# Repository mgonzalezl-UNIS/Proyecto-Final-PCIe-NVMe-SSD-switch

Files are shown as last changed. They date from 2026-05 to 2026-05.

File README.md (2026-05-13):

# Proyecto Final de Electrónica 2 y Diseño Electrónico 1 - PCIe to NVMe M.2 SSD Switch

<p align="center">
  <em>Universidad del Istmo de Guatemala</em><br>
  <em>Facultad de Ingeniería</em><br>
  <em>Proyecto Final</em><br>
  <em>Electrónica 2 y Diseño Electrónico 1</em>
</p>

<div align="center">
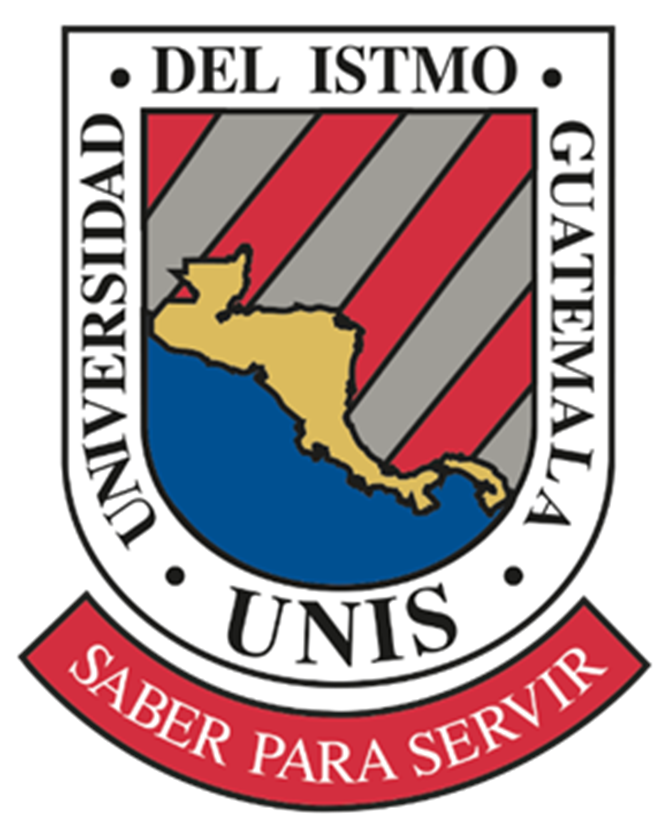
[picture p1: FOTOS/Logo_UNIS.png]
Logo UNIS
  
</div>

<p align="center">
  <em>Maximiliano González</em><br>
  <em>mayo de 2026</em>
</p>

## Descripción general

<div align="center">
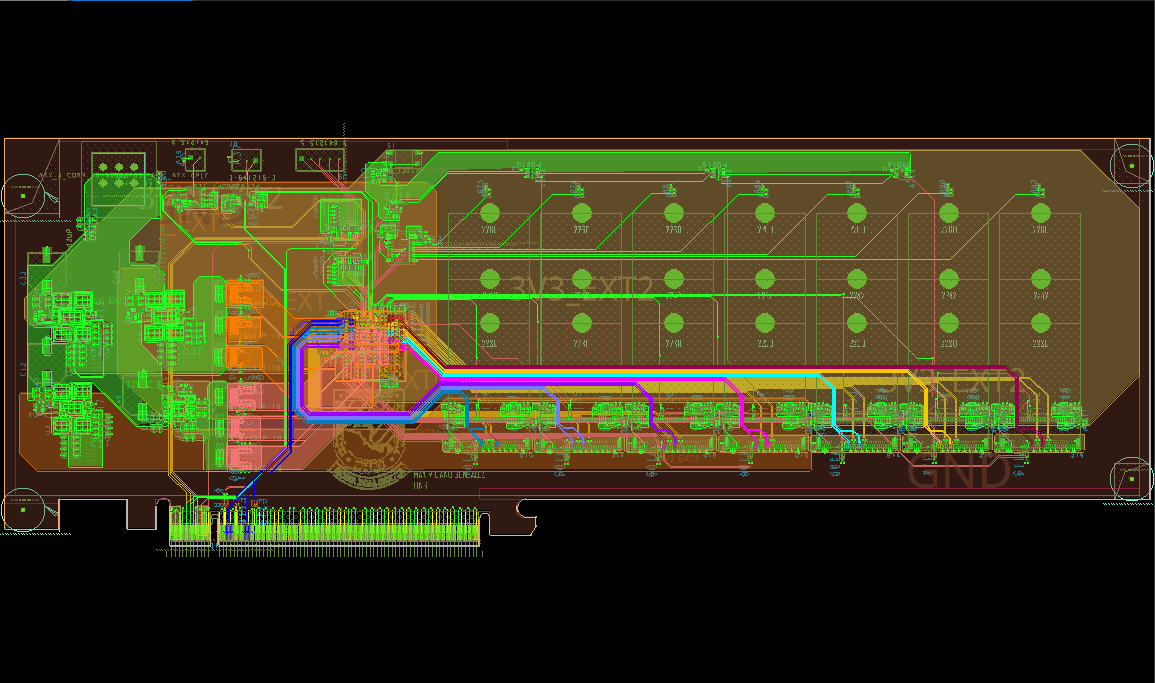
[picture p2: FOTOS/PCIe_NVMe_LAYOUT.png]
PCB LAYOUT
  
</div>

Este repositorio documenta el diseño de una tarjeta personalizada con **switch PCIe Gen 3 para expansión de SSDs NVMe M.2**. El objetivo del proyecto es tomar una conexión PCIe desde el host y distribuirla mediante un switch PCIe para conectar varios SSDs NVMe M.2 en una sola tarjeta.

La tarjeta se desarrolló como proyecto final de electrónica y se enfoca en el trabajo práctico necesario para un sistema PCIe de alta velocidad: captura esquemática, diseño del árbol de potencia, planeación de carriles PCIe, distribución del reloj de referencia, manejo de reset/wake/presence, bus SMBus/I2C, conectores M.2, restricciones de layout, stack-up e integración mecánica. Es importante notar que el diseno final **no** soporta **hot plug**.

## Tabla de Contenido

- [Versión en Español](#switch-pcie-a-nvme-m2-ssd)
  - [Descripción general](#descripción-general)
  - [Project Images](#project-images)
    - [Top Layer](#top-layer)
    - [GND02 Layer](#gnd02-layer)
    - [ART03 Layer](#art03-layer)
    - [ART04 Layer](#art04-layer)
    - [PWR05 Layer](#pwr05-layer)
    - [Bottom Layer](#bottom-layer)
  - [Concepto 3D](#concepto-3D)
    - [Isometric View](#isometric-view)
    - [Front View](#front-View)
    - [Back View](#back-view)
  - [Chip PCIe principal](#chip-pcie-principal)
  - [Objetivos del proyecto](#objetivos-del-proyecto)
  - [Arquitectura general](#arquitectura-general)
  - [Bloques principales del diseño](#bloques-principales-del-diseño)
    - [1. Interfaz PCIe upstream](#1-interfaz-pcie-upstream)
    - [2. Núcleo del switch PCIe](#2-núcleo-del-switch-pcie)
    - [3. Puertos downstream M.2 NVMe](#3-puertos-downstream-m2-nvme)
    - [4. Administración SMBus / I2C](#4-administración-smbus--i2c)
    - [5. Straps de configuración](#5-straps-de-configuración)
    - [6. Arquitectura de potencia](#6-arquitectura-de-potencia)
    - [7. Señales de reset, wake y presence](#7-señales-de-reset-wake-y-presence)
    - [8. Reloj de referencia](#8-reloj-de-referencia)
    - [9. Layout y restricciones de PCB](#9-layout-y-restricciones-de-pcb)
    - [10. Diseño mecánico](#10-diseño-mecánico)
  - [Filosofía de diseño](#filosofía-de-diseño)
  - [Herramientas utilizadas](#herramientas-utilizadas)
  - [Contenido sugerido del repositorio](#contenido-sugerido-del-repositorio)
  - [Estado actual](#estado-actual)
  - [Notas](#notas)

## Imagenes del proyecto

### Top Layer

<div align="center">
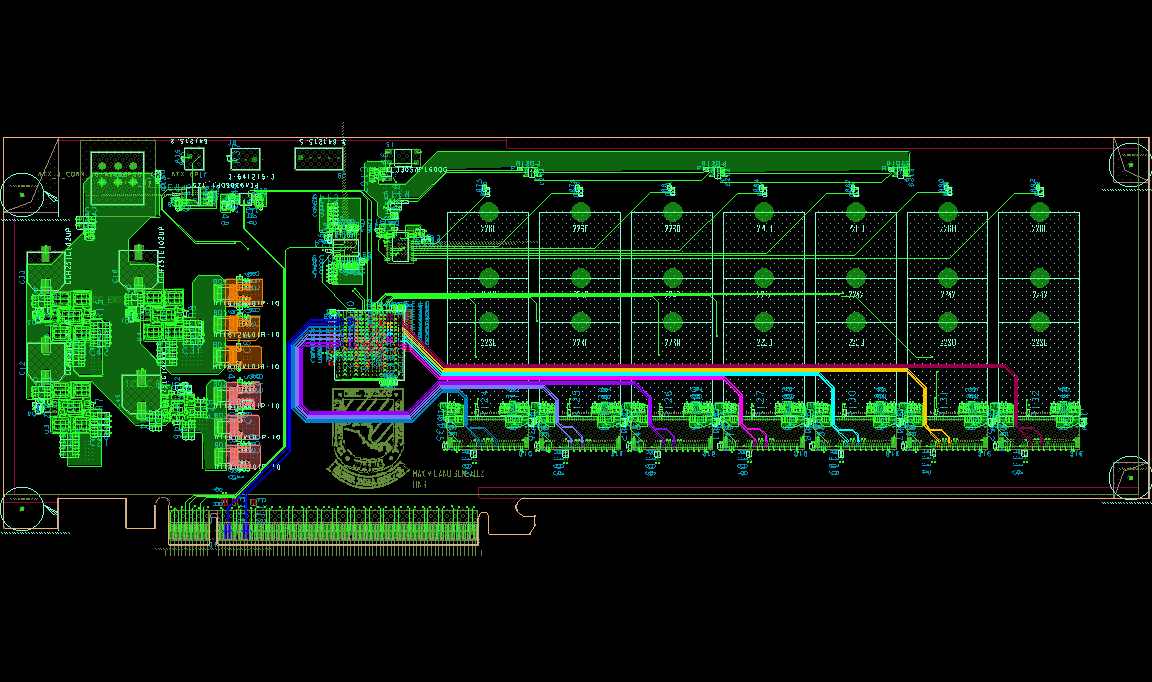
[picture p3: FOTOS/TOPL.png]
TOP LAYER
  
</div>

### GND02 Layer

<div align="center">
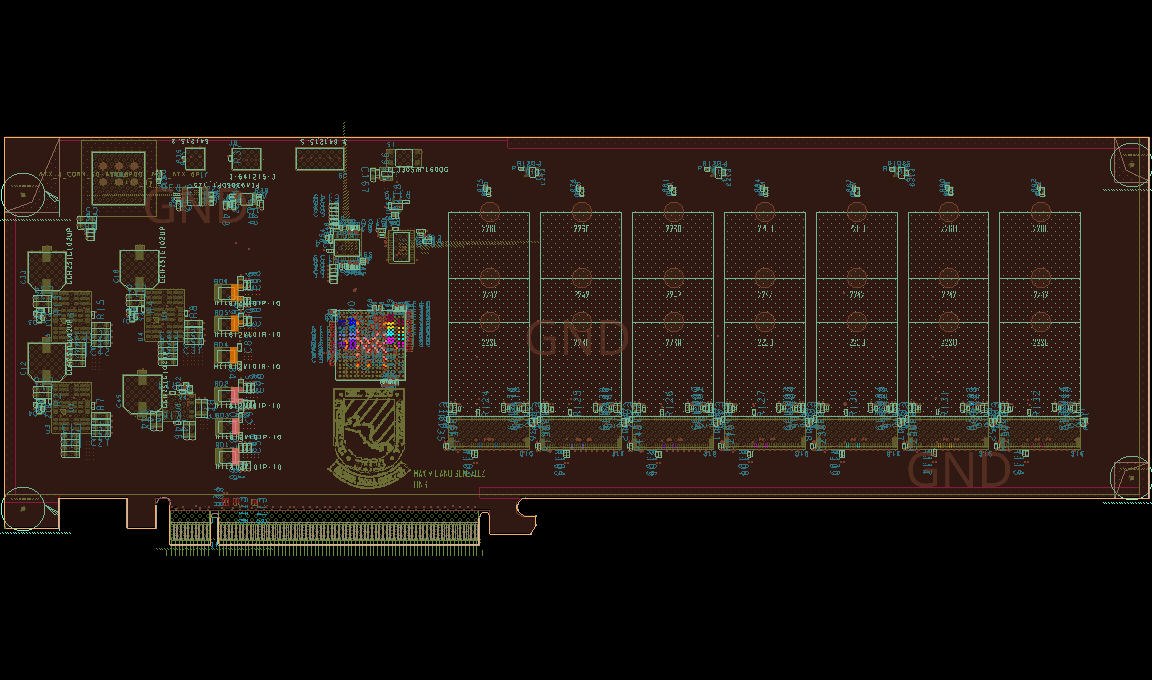
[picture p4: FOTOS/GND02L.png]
GND02 LAYER
  
</div>

### ART03 Layer

<div align="center">
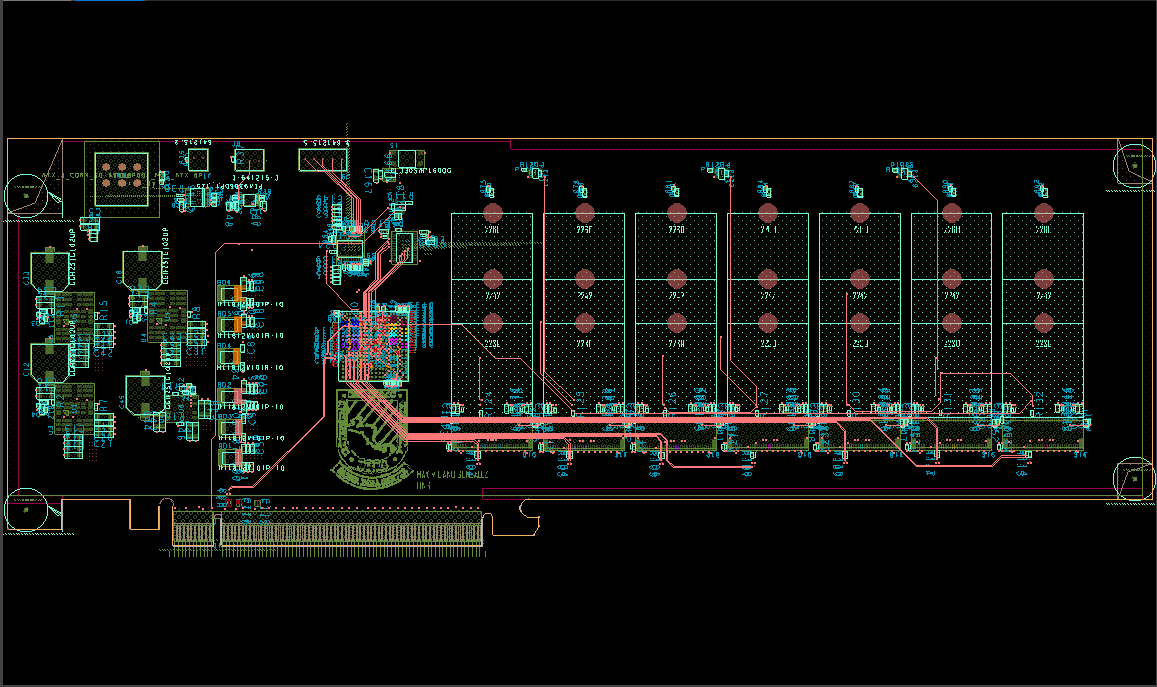
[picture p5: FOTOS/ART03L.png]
ART03 LAYER
  
</div>

### ART04 Layer

<div align="center">
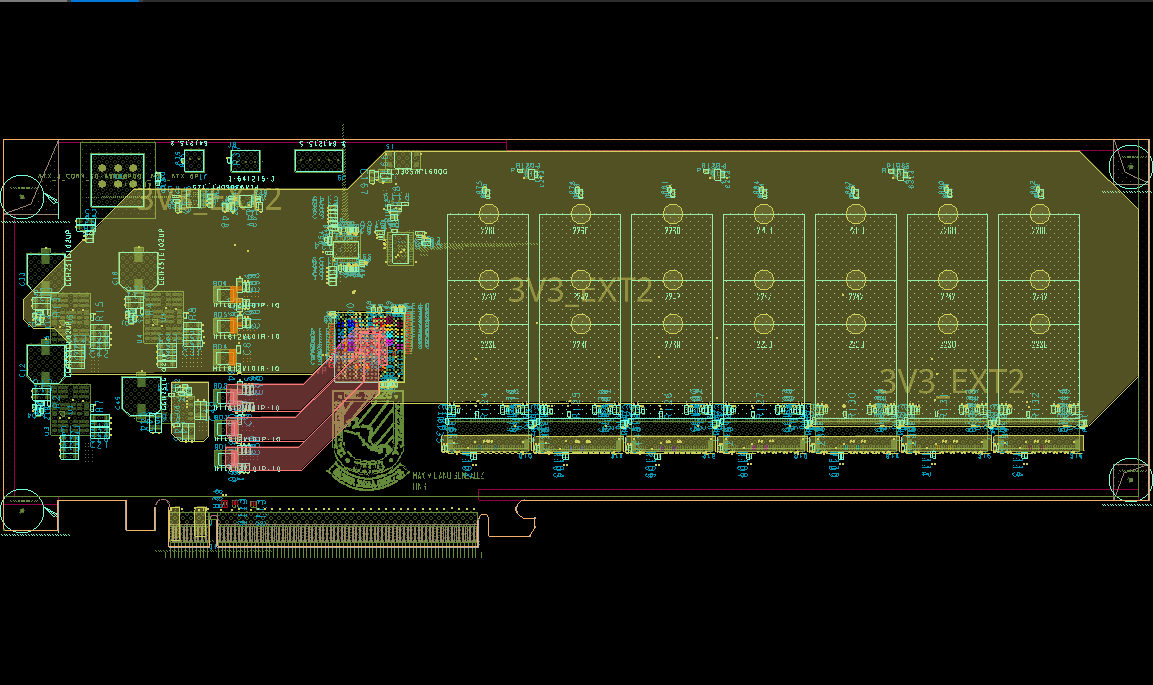
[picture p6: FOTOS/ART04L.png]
ART04 LAYER
  
</div>

### PWR05 Layer

<div align="center">
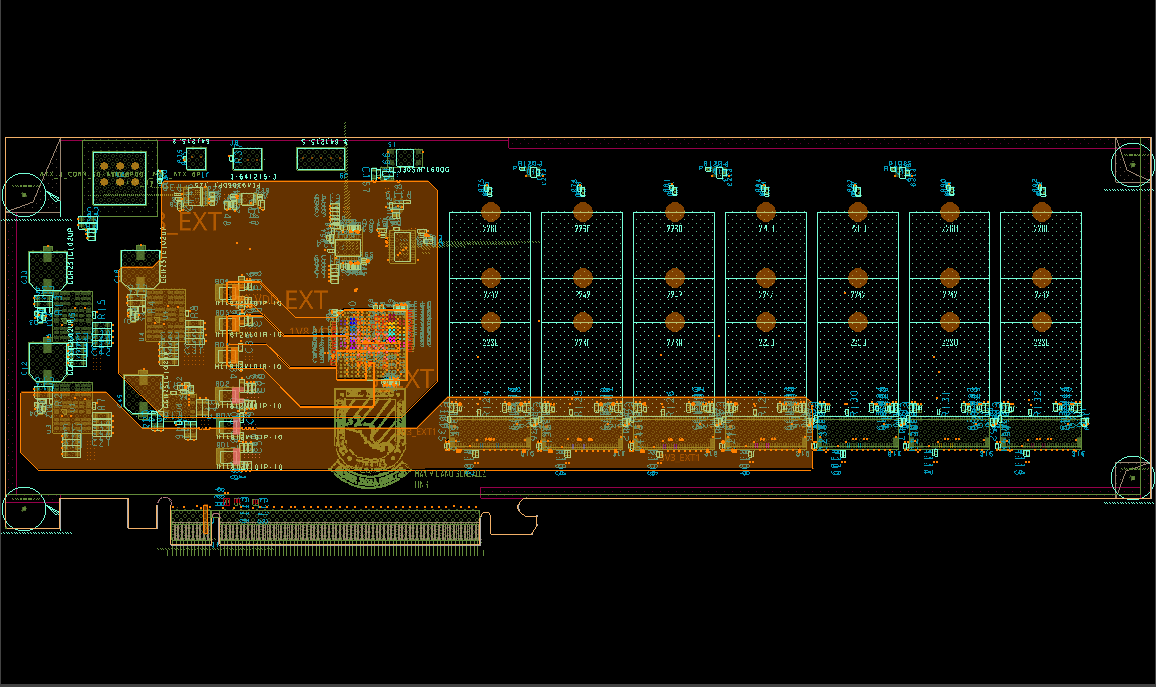
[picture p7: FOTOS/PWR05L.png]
PWR05 LAYER
  
</div>

### BOTTOM Layer

<div align="center">
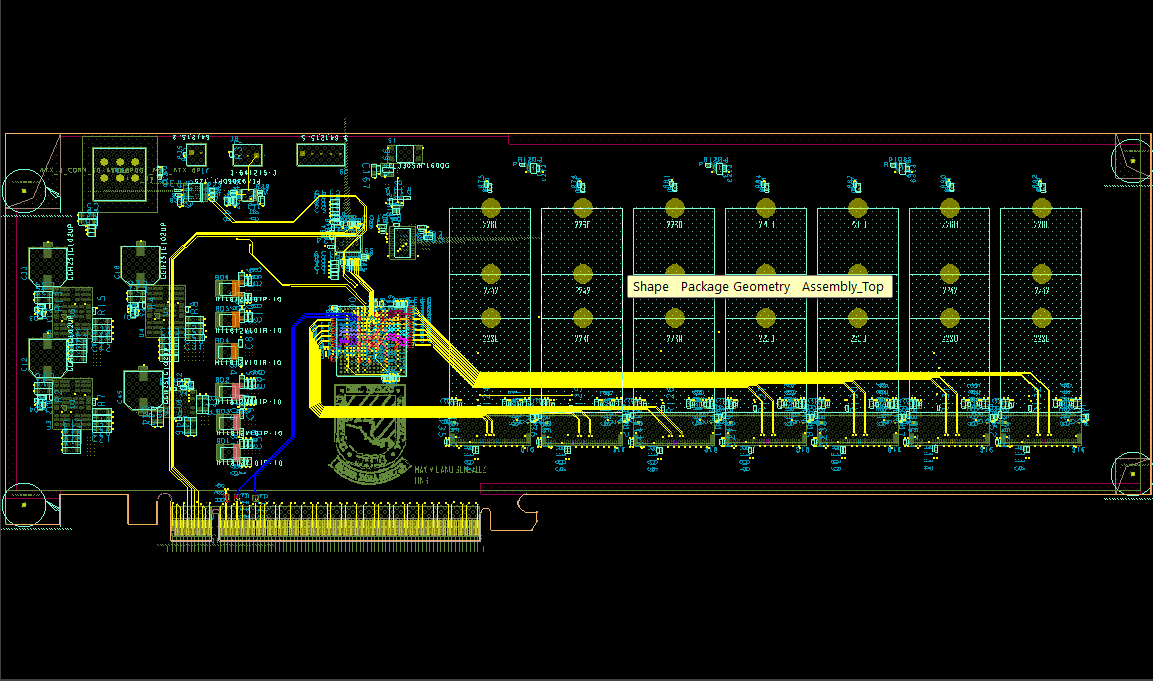
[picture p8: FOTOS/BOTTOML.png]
BOTTOM LAYER
  
</div>

## Concepto 3D

### Isometric View

<div align="center">
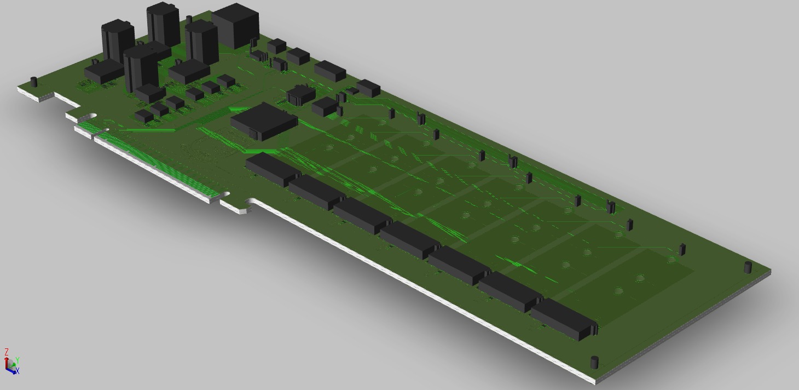
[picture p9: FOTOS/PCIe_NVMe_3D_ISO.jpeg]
3D Isometric View
  
</div>

### Front View

<div align="center">
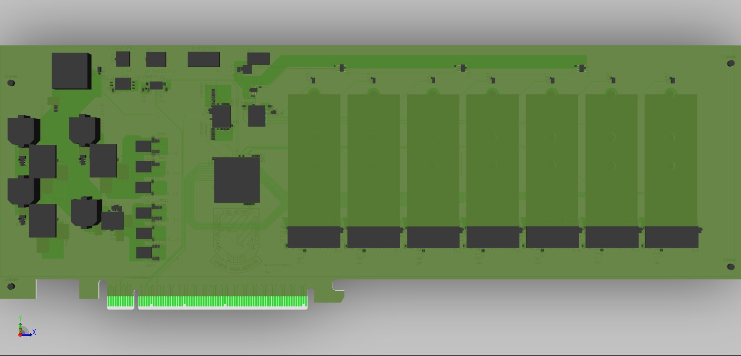
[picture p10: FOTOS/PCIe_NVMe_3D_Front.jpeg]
3D Front View
  
</div>

### Back View

<div align="center">
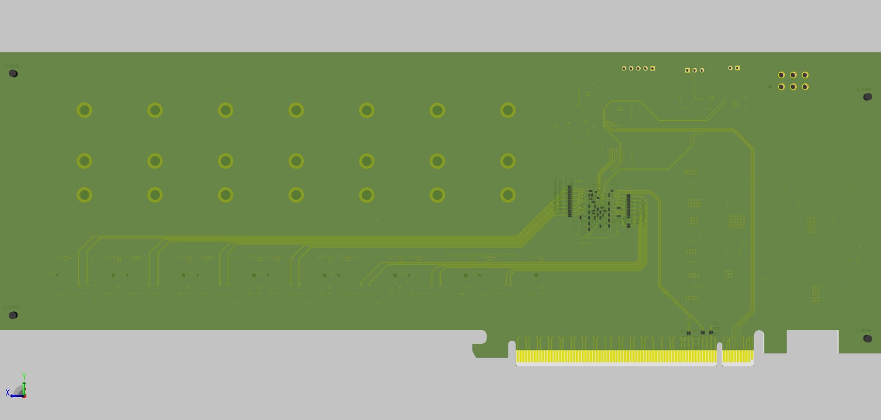
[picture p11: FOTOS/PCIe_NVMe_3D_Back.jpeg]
3D Back View
  
</div>

## Chip PCIe principal

<div align="center">
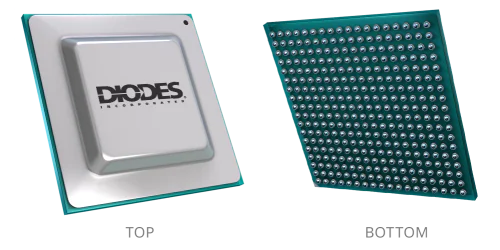
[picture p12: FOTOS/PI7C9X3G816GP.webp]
PI7C9X3G816GP Chip
  
</div>

El diseño está basado en el **Diodes Incorporated PI7C9X3G816GP**, un switch PCI Express Gen 3. En este proyecto, el switch se usa para conectar una interfaz PCIe upstream con varios puertos downstream para SSDs NVMe M.2.

Características relevantes usadas en este proyecto:

- Conmutación PCIe Gen 3 para expansión de almacenamiento NVMe.
- Configuración de puertos y carriles mediante los straps `PORTCFG_x[2:0]`.
- Particionamiento del switch mediante `SWP_MODE[1:0]`.
- Modo normal de operación con `CHIPMODE[1:0] = 00`.
- Operación con un solo reloj de referencia usando `CKMODE = 0` / modo BASE.
- Selección de SMBus o I2C mediante `SMBUS_EN_L`.
- Opción de JTAG/boundary scan mediante `JTAG_SEL_L`.
- Señales relacionadas con hot-plug y administración de bajo consumo revisadas, pero no usadas como modo principal de operación para la tarjeta M.2.

## Objetivos del proyecto

- Diseñar una tarjeta PCIe Gen 3 capaz de conectar múltiples SSDs NVMe M.2.
- Usar un formato mecánico tipo tarjeta PCIe full-height.
- Seguir el esquemático de referencia/EVB de Diodes donde sea útil, simplificando las partes que no son necesarias para el diseño final.
- Mantener los straps de configuración en estados definidos, sin pines flotantes.
- Usar modos habilitados por defecto con resistores DNP donde sea útil para depuración o cambios futuros.
- Crear una PCB manufacturable en Cadence OrCAD/Allegro.

## Arquitectura general

```text
Conector PCIe al host
        |
        | Enlace PCIe Gen 3 upstream
        |
+-----------------------------+
| Diodes PI7C9X3G816GP        |
| Switch PCIe Gen 3           |
+-----------------------------+
        |
        | Enlaces PCIe Gen 3 downstream
        |
+-------+-------+-------+----------------+
| M.2 1 | M.2 2 | M.2 3 | ... SSDs NVMe  |
+-------+-------+-------+----------------+
```

El switch recibe el enlace PCIe upstream desde el host y distribuye enlaces PCIe downstream hacia los conectores M-key M.2 NVMe. Cada conector SSD usa carriles PCIe, reloj de referencia, reset, presence, wake y señales relacionadas con SMBus/I2C según los requerimientos de M.2 y PCIe.

## Bloques principales del diseño

<div align="center">
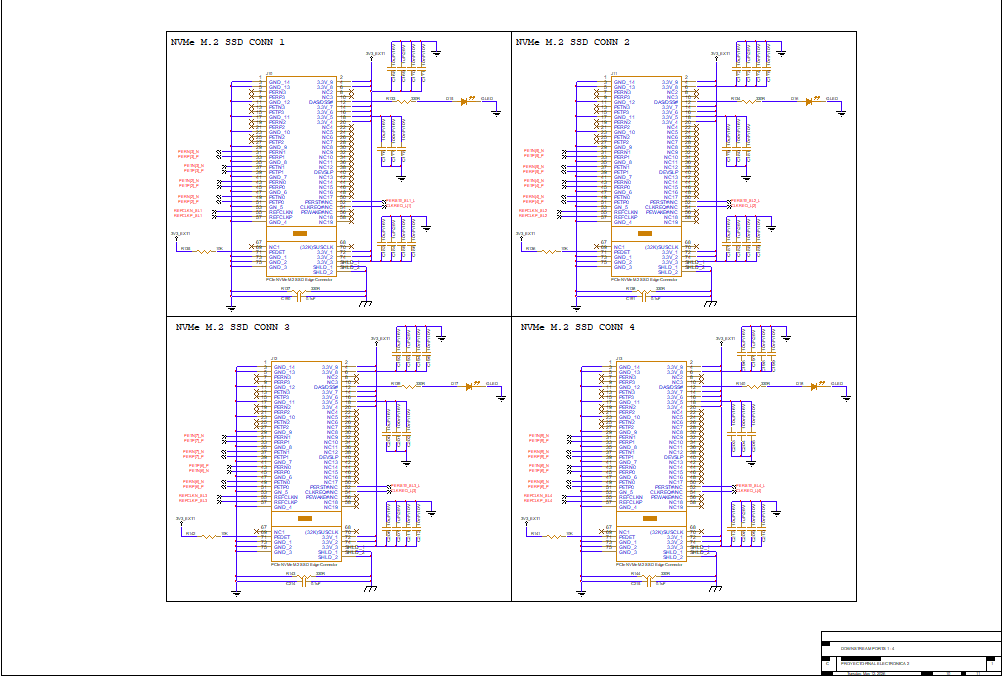
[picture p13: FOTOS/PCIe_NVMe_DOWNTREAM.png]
Schematic Downstream Ports 1 - 4
  
</div>

### 1. Interfaz PCIe upstream

La interfaz upstream conecta la tarjeta al sistema host mediante el conector PCIe edge. Esta sección incluye los pares diferenciales PCIe TX/RX, el reloj de referencia, reset, señales de wake/presence y los rieles de alimentación provenientes del conector host.

### 2. Núcleo del switch PCIe

El PI7C9X3G816GP es el componente central de la tarjeta. El trabajo de diseño alrededor de este IC incluye:

- Seleccionar la configuración correcta de puertos/carriles para la cantidad de SSDs NVMe.
- Definir valores de resistores de strap para los pines de modo.
- Rutear pares diferenciales PCIe de alta velocidad con impedancia controlada.
- Administrar entradas y salidas de reloj de referencia.
- Agregar desacople local cerca de los pines de alimentación del switch.
- Separar y filtrar rieles según lo requerido por el diseño de referencia.

### 3. Puertos downstream M.2 NVMe

Los puertos downstream usan conectores M-key M.2 para SSDs NVMe. Cada puerto incluye:

- Pares diferenciales PCIe TX/RX.
- Par REFCLK.
- Señal de reset `PERST#`.
- Manejo de `PEWAKE#` / `WAKE#`.
- Manejo de `PRSNT#` o señales de presencia cuando aplique.
- Capacitores locales de bulk y desacople de alta frecuencia.

### 4. Administración SMBus / I2C

El proyecto incluye soporte SMBus/I2C en lugar de dejar el bus de administración sin usar.

El switch permite seleccionar SMBus o I2C usando `SMBUS_EN_L`:

- Alto: modo I2C.
- Bajo: modo SMBus.

El diseño mantiene esta selección configurable con resistores para permitir un valor por defecto y también modificaciones durante bring-up.

### 5. Straps de configuración

Varios pines de configuración del switch se fijan con resistores pull-up o pull-down. Las decisiones del proyecto incluyen:

| Grupo de señales | Intención del proyecto |
|---|---|
| `CHIPMODE[1:0]` | Modo normal de operación, `00`. |
| `PORTCFG_x[2:0]` | Configurado según la distribución deseada de carriles downstream. |
| `CKMODE` | Operación con un solo reloj de referencia / estilo BASE. |
| `I2C_ADDR[2:0]` | Dirección por defecto `000`. |
| `JTAG_SEL_L` | Opción configurable para JTAG/boundary scan. |
| `SMBUS_EN_L` | Opción configurable para seleccionar SMBus o I2C. |

La EVB de referencia usa configuración mediante DIP switches, pero este proyecto reemplaza ese enfoque con straps fijos y opciones DNP donde es práctico.

### 6. Arquitectura de potencia

La tarjeta usa rieles de entrada PCIe/ATX y reguladores point-of-load locales para generar los voltajes requeridos por el switch PCIe y los conectores M.2.

El trabajo de potencia incluyó:

- Distribución de entrada de 12 V.
- Riel de 3.3 V para SSDs M.2 y lógica auxiliar.
- Rieles de 1.8 V y otros voltajes de núcleo requeridos por el switch PCIe.
- Selección de módulos POL con inductor integrado cuando fue posible.
- Capacitores bulk en los rieles de 12 V y 3.3 V.
- Desacople cerámico de alta frecuencia cerca de pines de alimentación.
- Indicadores LED usando NMOS para indicar estado de rieles/señales.

### 7. Señales de reset, wake y presence

El proyecto revisó las señales laterales PCIe necesarias para funcionamiento correcto:

- `PERST#`: distribución de reset hacia el switch y los dispositivos downstream.
- `PEWAKE#` / `WAKE#`: señal de wake desde dispositivos downstream.
- `PRSNT#`: detección de presencia o comportamiento relacionado con el conector.
- `INTA_L / PM_L11_EN_L`: revisada como parte del diseño de referencia; no tratada como señal principal de hot-plug para el diseño M.2 simplificado.

### 8. Reloj de referencia

El diseño usa distribución del reloj de referencia PCIe de acuerdo con la configuración seleccionada de `CKMODE`. Para el enfoque por defecto de un solo reloj de referencia, los carriles del switch se alimentan desde una fuente de reloj común. El ruteo diferencial de REFCLK se trata como ruteo de alta velocidad y debe cumplir las restricciones de impedancia y matching usadas para pares de reloj PCIe.

### 9. Layout y restricciones de PCB

La tarjeta se implementa en Cadence Allegro/OrCAD. El trabajo importante de layout incluye:

- Ruteo de pares diferenciales PCIe Gen 3.
- Impedancia controlada para pares TX/RX y REFCLK.
- Matching intra-par para pares diferenciales.
- Matching entre carriles donde lo requiera el Constraint Manager.
- Reglas de necking cerca del breakout del BGA y conectores.
- Selección de vías para fanout BGA y transiciones de alta velocidad.
- Creación de route keep-in y package keep-in.
- Planeación de bracket/mecánica full-height PCIe.
- Uso de exportación/importación de geometría en Allegro cuando fue útil.

### 10. Diseño mecánico

El trabajo mecánico incluyó:

- Planeación del contorno tipo tarjeta PCIe add-in-card.
- Consideración de bracket/faceplate full-height.
- Tamaño y ubicación de mounting holes.
- Geometría de package keep-in y route keep-in.
- Ubicación de conectores M.2 y clearances para SSDs.
- Flujo de importación/conversión de DXF y board outline en Allegro.

## Filosofía de diseño

La tarjeta sigue la EVB de referencia donde tiene sentido, pero elimina complejidad innecesaria para el proyecto final. Los DIP switches se reemplazan con straps de resistores, las opciones de debug se mantienen solo donde son útiles, y el diseño se optimiza para el caso de uso principal: un host PCIe conectado a múltiples SSDs NVMe M.2 mediante un switch PCIe Gen 3.

El diseño enfatiza defaults de hardware determinísticos, ruteo limpio de alta velocidad, desacople adecuado y manufacturabilidad práctica.

## Herramientas utilizadas

- Cadence OrCAD Capture para el esquemático.

<div align="left">
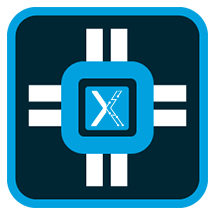
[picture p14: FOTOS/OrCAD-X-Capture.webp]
OrCad Capture Logo
  
</div>

- Cadence Allegro PCB Editor para layout.

<div align="left">
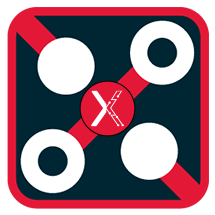
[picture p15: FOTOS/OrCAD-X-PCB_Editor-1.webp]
OrCad Allegro Logo
  
</div>

- Datasheet y documentación EVB del Diodes PI7C9X3G816GP como referencia.

<div align="left">
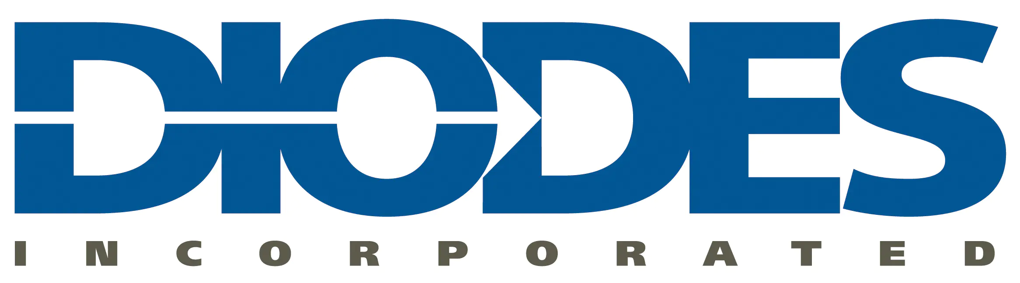
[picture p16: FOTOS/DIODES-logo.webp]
DIODES Inc. Logo
  
</div>

- Datasheets de fabricantes para reguladores, conectores, capacitores, resistores, MOSFETs y lógica.

## Contenido del repositorio

```text
```text
.
├── README(EN).md
├── README(ES).md
├── Schematic.pdf
├── BOARD TEMPLATE/
│   ├── CNV & DXF FILES/
│   └── PCIe_BOARD_TEMPLATE_FL.brd
├── BOM/
│   ├── BOM_PCIe_NVMe.BOM
│   └── BOM_PCIe_NVMe.BOM.xlsx
├── DRL/
│   └── pcie-nvme_rework2-1-6.drl
├── DSN & BRD/
│   ├── PCIE-NVME.DSN
│   └── pcie-nvme.brd
├── FOTOS/
│   ├── ART03L.png
│   ├── ART04L.png
│   ├── BOTTOML.png
│   ├── DIODES-logo.webp
│   ├── GND02L.png
│   ├── Logo_UNIS.png
│   ├── OrCAD-X-Capture.webp
│   ├── OrCAD-X-PCB_Editor-1.webp
│   ├── PCIe_NVMe_3D_Back.png
│   ├── PCIe_NVMe_3D_Front.png
│   ├── PCIe_NVMe_3D_ISO.png
│   ├── PCIe_NVMe_DOWNTREAM.png
│   ├── PCIe_NVMe_LAYOUT.png
│   ├── PI7C9X3G816GP.webp
│   ├── PWR05L.png
│   └── TOPL.png
├── GERBER/
│   ├── ART03L.art
│   ├── ART04L.art
│   ├── BOARD.art
│   ├── BOTTOML.art
│   ├── GND02L.art
│   ├── PASTEB.art
│   ├── PASTET.art
│   ├── PWR05L.art
│   ├── SILKB.art
│   ├── SILKT.art
│   ├── SOLDERB.art
│   ├── SOLDERT.art
│   └── TOPL.art
└── Referencias/
    ├── PI7C9X3G816GP-Design-kit-2.3.zip
    └── PI7C9X3G816GP-Support-kit-1.0.zip
```

## Estado actual

El trabajo del proyecto cubrió decisiones de esquemático, planeación de señales, selección de componentes, creación de footprints, configuración de restricciones en Allegro, planeación mecánica y guía de layout. La validación final debe incluir limpieza de DRC, verificación de impedancia con el stack-up seleccionado, revisión de todos los straps, revisión de secuencia de rieles y revisión completa de esquemático/layout antes de fabricación.

## Notas

Este proyecto es un diseño de hardware educativo. Antes de fabricar o usar la tarjeta con SSDs NVMe costosos, se deben revisar de forma independiente el ruteo de alta velocidad, los rieles de potencia, tiempos de reset, topología del reloj de referencia, pinouts de conectores y straps de configuración.

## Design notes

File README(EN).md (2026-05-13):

# Final Electronics 2 and Electronic Design 1 Project - PCIe to NVMe M.2 SSD Switch

<p align="center">
  <em>Universidad del Istmo de Guatemala</em><br>
  <em>Faculty of Engineering</em><br>
  <em>Final Project</em><br>
  <em>Electronics 2 and Electronic Design 1</em>
</p>

<div align="center">
  Logo UNIS
</div>

<p align="center">
  <em>Maximiliano González</em><br>
  <em>May 2026</em>
</p>

## Overview

<div align="center">
  PCB LAYOUT
</div>

This repository documents the design of a custom **PCIe Gen 3 switch board for NVMe M.2 SSD expansion**. The goal of the project is to take a PCIe host connection and fan it out through a PCIe switch so multiple NVMe M.2 SSDs can be connected on one board.

The board is intended as a final electronics 2 project and focuses on the practical design work required for a high-speed PCIe system: schematic capture, power-tree design, PCIe lane planning, reference-clock distribution, reset/wake/presence handling, SMBus/I2C management, M.2 connector implementation, layout constraints, stack-up planning, and mechanical integration. It is important to note that the final design **does not** support **hot plug**.

## Table of Contents

- [English Version](#pcie-to-nvme-m2-ssd-switch)
  - [Overview](#overview)
  - [Table of Contents](#table-of-contents)
  - [Project Images](#project-images)
    - [Top Layer](#top-layer)
    - [GND02 Layer](#gnd02-layer)
    - [ART03 Layer](#art03-layer)
    - [ART04 Layer](#art04-layer)
    - [PWR05 Layer](#pwr05-layer)
    - [Bottom Layer](#bottom-layer)
  - [3D Concept](#3D-concept)
    - [Isometric View](#isometric-view)
    - [Front View](#front-View)
    - [Back View](#back-view)
  - [Main PCIe Switch IC](#main-pcie-switch-ic)
  - [Project Goals](#project-goals)
  - [High-Level Architecture](#high-level-architecture)
  - [Major Design Blocks](#major-design-blocks)
    - [1. PCIe Upstream Interface](#1-pcie-upstream-interface)
    - [2. PCIe Switch Core](#2-pcie-switch-core)
    - [3. Downstream M.2 NVMe Ports](#3-downstream-m2-nvme-ports)
    - [4. SMBus / I2C Management](#4-smbus--i2c-management)
    - [5. Configuration Straps](#5-configuration-straps)
    - [6. Power Architecture](#6-power-architecture)
    - [7. Reset, Wake, and Presence Signals](#7-reset-wake-and-presence-signals)
    - [8. Reference Clocking](#8-reference-clocking)
    - [9. PCB Layout and Constraints](#9-pcb-layout-and-constraints)
    - [10. Mechanical Design](#10-mechanical-design)
  - [Design Philosophy](#design-philosophy)
  - [Tools Used](#tools-used)
  - [Repository Contents](#repository-contents)
  - [Current Status](#current-status)
  - [Notes](#notes)

## Project Images

### Top Layer

<div align="center">
  TOP LAYER
</div>

### GND02 Layer

<div align="center">
  GND02 LAYER
</div>

### ART03 Layer

<div align="center">
  ART03 LAYER
</div>

### ART04 Layer

<div align="center">
  ART04 LAYER
</div>

### PWR05 Layer

<div align="center">
  PWR05 LAYER
</div>

### BOTTOM Layer

<div align="center">
  BOTTOM LAYER
</div>

## 3D Concept

### Isometric View

<div align="center">
  3D Isometric View
</div>

### Front View

<div align="center">
  3D Front View
</div>

### Back View

<div align="center">
  3D Back View
</div>

## Main PCIe Switch IC

<div align="center">
  PI7C9X3G816GP Chip
</div>

The design is based around the **Diodes Incorporated PI7C9X3G816GP**, a PCI Express Gen 3 packet switch. In this project, the switch is used to connect one upstream PCIe interface to multiple downstream NVMe M.2 SSD ports.

Relevant switch features used by this project include:

- PCIe Gen 3 switching for high-speed NVMe storage expansion.
- Multi-lane port configuration through `PORTCFG_x[2:0]` strap pins.
- Switch partitioning through `SWP_MODE[1:0]`.
- Normal operating mode selected through `CHIPMODE[1:0] = 00`.
- Single-reference-clock style operation selected with `CKMODE = 0` / BASE mode.
- SMBus or I2C management selection through `SMBUS_EN_L`.
- Optional JTAG/boundary-scan configuration through `JTAG_SEL_L`.
- Hot-plug and low-power-management related signals reviewed but not used as the primary operating mode for the M.2 SSD board.

## Project Goals

- Design a PCIe Gen 3 switch board that can host multiple NVMe M.2 SSDs.
- Use a full-height PCIe add-in-card style mechanical format.
- Follow the Diodes evaluation board/reference schematic where useful, while simplifying parts that are not needed for the final design.
- Keep configuration straps deterministic instead of relying on floating pins.
- Use default-enabled operating modes with optional DNP resistor positions where useful for debugging or future changes.
- Build a manufacturable PCB in Cadence OrCAD/Allegro.

## High-Level Architecture

```text
Host PCIe Edge Connector
        |
        | Upstream PCIe Gen 3 link
        |
+-----------------------------+
| Diodes PI7C9X3G816GP        |
| PCIe Gen 3 Packet Switch    |
+-----------------------------+
        |
        | Downstream PCIe Gen 3 links
        |
+-------+-------+-------+----------------+
| M.2 1 | M.2 2 | M.2 3 | ... NVMe SSDs  |
+-------+-------+-------+----------------+
```

The switch receives the upstream PCIe link from the host and distributes downstream PCIe links to the M-key M.2 NVMe SSD connectors. Each SSD connector uses PCIe lanes, reference clock, reset, presence, wake, and SMBus/I2C-related signals as required by the M.2 and PCIe design.

## Major Design Blocks

<div align="center">
  Schematic Downstream Ports 1 - 4
</div>

### 1. PCIe Upstream Interface

The upstream interface connects the board to the host system through a PCIe edge connector. This side includes the upstream PCIe transmit/receive differential pairs, reference clock input, reset, wake/presence-related signals, and the required power rails from the host connector.

### 2. PCIe Switch Core

The PI7C9X3G816GP is the central component of the board. Important design work around this IC includes:

- Selecting the correct port/lane configuration for the number of NVMe SSDs.
- Defining strap resistor values for mode pins.
- Routing high-speed PCIe differential pairs with controlled impedance.
- Managing reference-clock inputs and outputs.
- Adding local decoupling close to the switch power pins.
- Separating and filtering rails as required by the reference design.

### 3. Downstream M.2 NVMe Ports

The downstream ports use M-key M.2 connectors for NVMe SSDs. Each port includes:

- PCIe TX/RX differential pairs.
- REFCLK pair.
- PERST# reset signal.
- PEWAKE#/WAKE# handling.
- PRSNT#/presence-related handling where applicable.
- Local bulk and high-frequency decoupling.

### 4. SMBus / I2C Management

The project includes SMBus/I2C support instead of leaving the management bus unused. 

The switch supports selecting between SMBus and I2C using `SMBUS_EN_L`:

- High: I2C mode.
- Low: SMBus mode.

The design keeps this selection configurable with resistor options so the board can follow the desired default while still allowing modification during bring-up.

### 5. Configuration Straps

Several switch configuration pins are strapped with pull-up or pull-down resistors. The project decisions include:

| Signal Group | Project Intent |
|---|---|
| `CHIPMODE[1:0]` | Normal operating mode, `00`. |
| `PORTCFG_x[2:0]` | Set according to the desired downstream lane distribution. |
| `CKMODE` | Single reference clock / BASE-style operation. |
| `I2C_ADDR[2:0]` | Default address option set to `000`. |
| `JTAG_SEL_L` | Configurable option for boundary-scan/JTAG behavior. |
| `SMBUS_EN_L` | Configurable option for SMBus vs I2C selection. |

The reference EVB uses DIP-switch style configuration, but this project replaces that approach with fixed resistor straps and DNP options where practical.

### 6. Power Architecture

The board uses the PCIe/ATX input rails and local point-of-load regulators to generate the rails needed by the PCIe switch and M.2 connectors.

Power-design work included:

- 12 V input distribution.
- 3.3 V rail for M.2 SSDs and supporting logic.
- 1.8 V and lower-voltage switch-core rails as required by the PCIe switch.
- POL module selection with integrated inductors where possible.
- Bulk capacitors on 12 V and 3.3 V rails.
- High-frequency ceramic decoupling near IC power pins.
- LED indicators using NMOS switching for rail/status indication.

### 7. Reset, Wake, and Presence Signals

The project reviewed the PCIe sideband signals needed for correct behavior:

- `PERST#`: reset distribution to the switch and downstream devices.
- `PEWAKE#` / `WAKE#`: wake signaling from downstream devices.
- `PRSNT#`: presence detection or connector-related presence behavior.
- `INTA_L / PM_L11_EN_L`: reviewed as part of the reference design; not treated as a primary hot-plug signal for the final simplified M.2 switch use case.

### 8. Reference Clocking

The design uses PCIe reference-clock distribution consistent with the selected `CKMODE` configuration. For the default single-reference-clock approach, the switch tile lanes are driven from a shared clock source. Differential REFCLK routing is treated as high-speed routing and should follow the impedance and length-matching constraints used for PCIe clock pairs.

### 9. PCB Layout and Constraints

The board is implemented in Cadence Allegro/OrCAD. Important layout work includes:

- PCIe Gen 3 differential-pair routing.
- Controlled-impedance routing for TX/RX and REFCLK pairs.
- Differential-pair intra-pair matching.
- Lane-to-lane matching where required by the constraint manager.
- Necking rules near BGA breakout and connector regions.
- Via selection for BGA fanout and high-speed transitions.
- Route keep-in and package keep-in creation.
- Full-height PCIe bracket/mechanical outline planning.
- Use of Allegro board-geometry export/import where helpful.

### 10. Mechanical Design

Mechanical work included:

- PCIe add-in-card outline planning.
- Full-height bracket/faceplate consideration.
- Mounting-hole sizing and placement.
- Package keep-in and route keep-in geometry.
- M.2 connector placement and SSD clearance.
- Board-outline and DXF conversion/import workflow in Allegro.

## Design Philosophy

This board follows the evaluation board where it makes sense, but removes unnecessary complexity for the final project. DIP switches are replaced with resistor straps, debug options are kept only where useful, and the design is optimized around the intended use case: a PCIe host connected to multiple NVMe M.2 SSDs through a PCIe Gen 3 switch.

The design emphasizes deterministic hardware defaults, clean high-speed routing, adequate decoupling, and practical manufacturability.

## Tools Used

- Cadence OrCAD Capture for schematic design.

<div align="left">
  OrCad Capture Logo
</div>

- Cadence Allegro PCB Editor for layout.

<div align="left">
  OrCad Allegro Logo
</div>

- Diodes PI7C9X3G816GP datasheet and EVB documentation as references.

<div align="left">
  DIODES Inc. Logo
</div>

- Manufacturer datasheets for regulators, connectors, capacitors, resistors, MOSFETs, and logic devices.

## Repository Contents

```text
.
├── README(EN).md
├── README(ES).md
├── Schematic.pdf
├── BOARD TEMPLATE/
│   ├── CNV & DXF FILES/
│   └── PCIe_BOARD_TEMPLATE_FL.brd
├── BOM/
│   ├── BOM_PCIe_NVMe.BOM
│   └── BOM_PCIe_NVMe.BOM.xlsx
├── DRL/
│   └── pcie-nvme_rework2-1-6.drl
├── DSN & BRD/
│   ├── PCIE-NVME.DSN
│   └── pcie-nvme.brd
├── FOTOS/
│   ├── ART03L.png
│   ├── ART04L.png
│   ├── BOTTOML.png
│   ├── DIODES-logo.webp
│   ├── GND02L.png
│   ├── Logo_UNIS.png
│   ├── OrCAD-X-Capture.webp
│   ├── OrCAD-X-PCB_Editor-1.webp
│   ├── PCIe_NVMe_3D_Back.png
│   ├── PCIe_NVMe_3D_Front.png
│   ├── PCIe_NVMe_3D_ISO.png
│   ├── PCIe_NVMe_DOWNTREAM.png
│   ├── PCIe_NVMe_LAYOUT.png
│   ├── PI7C9X3G816GP.webp
│   ├── PWR05L.png
│   └── TOPL.png
├── GERBER/
│   ├── ART03L.art
│   ├── ART04L.art
│   ├── BOARD.art
│   ├── BOTTOML.art
│   ├── GND02L.art
│   ├── PASTEB.art
│   ├── PASTET.art
│   ├── PWR05L.art
│   ├── SILKB.art
│   ├── SILKT.art
│   ├── SOLDERB.art
│   ├── SOLDERT.art
│   └── TOPL.art
└── Referencias/
    ├── PI7C9X3G816GP-Design-kit-2.3.zip
    └── PI7C9X3G816GP-Support-kit-1.0.zip
```

## Current Status

The project work covered schematic decisions, signal planning, component selection, footprint creation, Allegro constraint setup, mechanical planning, and PCB layout guidance. Final validation should include DRC cleanup, impedance verification with the selected stack-up, review of all strap defaults, power-rail sequencing checks, and pre-fabrication schematic/layout review.

## Notes

This project is an educational hardware design project. Before manufacturing or using the board with expensive NVMe SSDs, all high-speed routing, power rails, reset timing, reference-clock topology, connector pinouts, and configuration straps should be independently reviewed.

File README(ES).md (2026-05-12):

# Proyecto Final de Electrónica 2 y Diseño Electrónico 1 - PCIe to NVMe M.2 SSD Switch

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

<div align="center">
  Logo UNIS
</div>

<p align="center">
  <em>Maximiliano González</em><br>
  <em>mayo de 2026</em>
</p>

## Descripción general

<div align="center">
  PCB LAYOUT
</div>

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

La tarjeta se desarrolló como proyecto final de electrónica y se enfoca en el trabajo práctico necesario para un sistema PCIe de alta velocidad: captura esquemática, diseño del árbol de potencia, planeación de carriles PCIe, distribución del reloj de referencia, manejo de reset/wake/presence, bus SMBus/I2C, conectores M.2, restricciones de layout, stack-up e integración mecánica. Es importante notar que no el diseno final **no** soporta **hot plug**.

## Tabla de Contenido

- [Versión en Español](#switch-pcie-a-nvme-m2-ssd)
  - [Descripción general](#descripción-general)
  - [Project Images](#project-images)
    - [Top Layer](#top-layer)
    - [GND02 Layer](#gnd02-layer)
    - [ART03 Layer](#art03-layer)
    - [ART04 Layer](#art04-layer)
    - [PWR05 Layer](#pwr05-layer)
    - [Bottom Layer](#bottom-layer)
  - [Chip PCIe principal](#chip-pcie-principal)
  - [Objetivos del proyecto](#objetivos-del-proyecto)
  - [Arquitectura general](#arquitectura-general)
  - [Bloques principales del diseño](#bloques-principales-del-diseño)
    - [1. Interfaz PCIe upstream](#1-interfaz-pcie-upstream)
    - [2. Núcleo del switch PCIe](#2-núcleo-del-switch-pcie)
    - [3. Puertos downstream M.2 NVMe](#3-puertos-downstream-m2-nvme)
    - [4. Administración SMBus / I2C](#4-administración-smbus--i2c)
    - [5. Straps de configuración](#5-straps-de-configuración)
    - [6. Arquitectura de potencia](#6-arquitectura-de-potencia)
    - [7. Señales de reset, wake y presence](#7-señales-de-reset-wake-y-presence)
    - [8. Reloj de referencia](#8-reloj-de-referencia)
    - [9. Layout y restricciones de PCB](#9-layout-y-restricciones-de-pcb)
    - [10. Diseño mecánico](#10-diseño-mecánico)
  - [Filosofía de diseño](#filosofía-de-diseño)
  - [Herramientas utilizadas](#herramientas-utilizadas)
  - [Contenido sugerido del repositorio](#contenido-sugerido-del-repositorio)
  - [Estado actual](#estado-actual)
  - [Notas](#notas)

## Imagenes del proyecto

### Top Layer

<div align="center">
  TOP LAYER
</div>

### GND02 Layer

<div align="center">
  GND02 LAYER
</div>

### ART03 Layer

<div align="center">
  ART03 LAYER
</div>

### ART04 Layer

<div align="center">
  ART04 LAYER
</div>

### PWR05 Layer

<div align="center">
  PWR05 LAYER
</div>

### BOTTOM Layer

<div align="center">
  BOTTOM LAYER
</div>

## Chip PCIe principal

<div align="center">
  PI7C9X3G816GP Chip
</div>

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

Características relevantes usadas en este proyecto:

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

## Objetivos del proyecto

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

## Arquitectura general

```text
Conector PCIe al host
        |
        | Enlace PCIe Gen 3 upstream
        |
+-----------------------------+
| Diodes PI7C9X3G816GP        |
| Switch PCIe Gen 3           |
+-----------------------------+
        |
        | Enlaces PCIe Gen 3 downstream
        |
+-------+-------+-------+----------------+
| M.2 1 | M.2 2 | M.2 3 | ... SSDs NVMe  |
+-------+-------+-------+----------------+
```

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

## Bloques principales del diseño

<div align="center">
  Schematic Downstream Ports 1 - 4
</div>

### 1. Interfaz PCIe upstream

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

### 2. Núcleo del switch PCIe

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

### 3. Puertos downstream M.2 NVMe

Los puertos downstream usan conectores M-key M.2 para SSDs NVMe. Cada puerto incluye:

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

### 4. Administración SMBus / I2C

El proyecto incluye soporte SMBus/I2C en lugar de dejar el bus de administración sin usar.

El switch permite seleccionar SMBus o I2C usando `SMBUS_EN_L`:

- Alto: modo I2C.
- Bajo: modo SMBus.

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

### 5. Straps de configuración

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

### 6. Arquitectura de potencia

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

El trabajo de potencia incluyó:

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

### 7. Señales de reset, wake y presence

El proyecto revisó las señales laterales PCIe necesarias para funcionamiento correcto:

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

### 8. Reloj de referencia

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

### 9. Layout y restricciones de PCB

La tarjeta se implementa en Cadence Allegro/OrCAD. El trabajo importante de layout incluye:

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

### 10. Diseño mecánico

El trabajo mecánico incluyó:

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

## Filosofía de diseño

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

## Herramientas utilizadas

- Cadence OrCAD Capture para el esquemático.

<div align="center">
  OrCad Capture Logo
</div>

- Cadence Allegro PCB Editor para layout.

<div align="center">
  OrCad Allegro Logo
</div>

- Datasheet y documentación EVB del Diodes PI7C9X3G816GP como referencia.

<div align="center">
  DIODES Inc. Logo
</div>

- Datasheets de fabricantes para reguladores, conectores, capacitores, resistores, MOSFETs y lógica.

## Contenido del repositorio

```text
```text
.
├── README(EN).md
├── README(ES).md
├── Schematic.pdf
├── BOARD TEMPLATE/
│   ├── CNV & DXF FILES/
│   └── PCIe_BOARD_TEMPLATE_FL.brd
├── BOM/
│   ├── BOM_PCIe_NVMe.BOM
│   └── BOM_PCIe_NVMe.BOM.xlsx
├── DRL/
│   └── pcie-nvme_rework2-1-6.drl
├── DSN & BRD/
│   ├── PCIE-NVME.DSN
│   └── pcie-nvme.brd
├── FOTOS/
│   ├── ART03L.png
│   ├── ART04L.png
│   ├── BOTTOML.png
│   ├── DIODES-logo.webp
│   ├── GND02L.png
│   ├── Logo_UNIS.png
│   ├── OrCAD-X-Capture.webp
│   ├── OrCAD-X-PCB_Editor-1.webp
│   ├── PCIe_NVMe_DOWNTREAM.png
│   ├── PCIe_NVMe_LAYOUT.png
│   ├── PI7C9X3G816GP.webp
│   ├── PWR05L.png
│   └── TOPL.png
├── GERBER/
│   ├── ART03L.art
│   ├── ART04L.art
│   ├── BOARD.art
│   ├── BOTTOML.art
│   ├── GND02L.art
│   ├── PASTEB.art
│   ├── PASTET.art
│   ├── PWR05L.art
│   ├── SILKB.art
│   ├── SILKT.art
│   ├── SOLDERB.art
│   ├── SOLDERT.art
│   └── TOPL.art
└── Referencias/
    ├── PI7C9X3G816GP-Design-kit-2.3.zip
    └── PI7C9X3G816GP-Support-kit-1.0.zip
```

## Estado actual

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

## Notas

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

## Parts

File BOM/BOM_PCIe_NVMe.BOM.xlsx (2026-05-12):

Revised: Friday, April 24, 2026
Revision: 1
Bill Of Materials May 11,2026
Item | Quantity | Reference | Part | Manufacturer | Manufacturer Part Number | JLCPCB Part Number
1 | 6 | BD1,BD2,BD3,BD4,BD5,BD6 | HI1812V101R-10 | Laird | HI1812V101R-10 | C2442066
2 | 1 | C1 | 10uF/16V | YAGEO | CC0805MKX7R7BB106 | C1952587
3 | 16 | C2,C4,C7,C8,C9,C148,C149,C150,C151,C152,C154,C156,C157,C158,C159,C166 | 0.1uF/50V | YAGEO | CC0603KRX7R9BB104 | C14663
4 | 3 | C3,C5,C6 | 10uF/25V | YAGEO | CC1206KKX5R8BB106 | C128855
5 | 8 | C10,C11,C17,C28,C32,C34,C43,C44 | 22uF/25V | YAGEO | CC1206KKX5R8BB226 | C2178233
6 | 4 | C12,C18,C33,C45 | 1000uF/25V | PANASONIC | EEH-ZS1E102UP | C6547400
7 | 28 | C13,C14,C15,C16,C19,C20,C21,C22,C23,C24,C25,C26,C27,C29,C30,C31,C35,C36,C37,C38,C39,C40,C41,C42,C46,C47,C48,C49 | 100uF/6.3V | YAGEO | CC1206MKX5R5BB107 | C110048
8 | 14 | C50,C55,C60,C69,C74,C80,C84,C87,C88,C97,C102,C142,C144,C160 | 10uF/6.3V | YAGEO | CC0603KRX5R5BB106 | C109455
9 | 11 | C51,C56,C61,C70,C75,C81,C85,C89,C91,C98,C103 | 4.7uF/6.3V | YAGEO | CC0603MRX7R5BB475 | C1952593
10 | 31 | C52,C53,C54,C57,C58,C59,C62,C63,C64,C71,C72,C73,C76,C77,C78,C82,C83,C86,C90,C92,C93,C94,C99,C100,C104,C106,C108,C146,C147,C161,C162 | 0.1uF/6.3V | YAGEO | CC0402KRX7R5BB104 | C541406
11 | 6 | C65,C66,C67,C68,C107,C109 | X_100uF/6.3V | YAGEO | CC1206MKX5R5BB107 | C110048
12 | 4 | C79,C96,C101,C105 | 47uF/6.3v |  | CC0805MKX5R5BB476 | C109461
13 | 1 | C95 | 47uF/6.3v | YAGEO | CC0805MKX5R5BB476 | C109461
14 | 32 | C110,C111,C112,C113,C114,C115,C116,C117,C118,C119,C120,C121,C122,C123,C124,C125,C126,C127,C128,C129,C130,C131,C132,C133,C134,C135,C136,C137,C138,C139,C140,C141 | 0.22uF/16V | TDK | C1005X7R1C224K050BE | C2169019
15 | 2 | C143,C163 | 10uF/10V | YAGEO | CC0603KRX5R6BB106 | C326057
16 | 3 | C145,C164,C165 | 0.1uF/10V | YAGEO | CC0402KRX7R6BB104 | C309458
17 | 23 | C153,C155,C168,C172,C176,C179,C183,C187,C192,C196,C200,C203,C206,C213,C216,C220,C224,C227,C230,C234,C240,C244,C247 | 10uF/16V | YAGEO | CC0603KRX5R7BB106 | C2936601
18 | 1 | C167 | 10uF/16V | YAGEO | CC0805KKX5R7BB106 | C89827
19 | 14 | C169,C173,C182,C184,C193,C197,C207,C208,C217,C221,C231,C235,C241,C248 | 1uF/25V | YAGEO | AC0603KRX7R8BB105 | C726560
20 | 35 | C170,C171,C174,C175,C178,C181,C185,C186,C188,C189,C194,C195,C198,C199,C202,C205,C209,C210,C211,C212,C218,C219,C222,C223,C226,C229,C232,C233,C236,C237,C242,C243,C246,C249,C250 | 10nF/10V | YAGEO | CC0402KRX7R6BB103 | C541371
21 | 7 | C177,C180,C201,C204,C225,C228,C245 | 100nF/16V | YAGEO | CC0402KRX7R7BB104
22 | 7 | C190,C191,C214,C215,C238,C239,C251 | 0.1uF | MURATA | GRM155R71H104KE14D | C77020
23 | 20 | D1,D2,D3,D4,D5,D7,D8,D9,D10,D11,D12,D13,D14,D15,D16,D17,D18,D19,D20,D21 | G-LED | Inolux | IN-S42ATG | C5197660
24 | 1 | D6 | RED | Inolux | IN-S42ATR | C7288933
25 | 1 | IC1 | PCA9306DP1,125 | NXP Semicon | PCA9306DP1,125 | C128835
26 | 1 | J1 | PCIe x16 EDGE
27 | 1 | J2 | CON2 | JST | BM02B-GHS-TBT | C20088623
28 | 4 | J3,J4,J5,J7 | X_CON2 | TE Connectivity | 641215-2 | C17668922
29 | 1 | J6 | X_CON4 | TE Connectivity | 641215-2 | C17668922
30 | 1 | J8 | CON_3P | TE Connectivity | 3-641215-3 | C305793
31 | 1 | J9 | X_CON5 | TE Connectivity | 3-641215-5 | C305794
32 | 7 | J10,J11,J12,J13,J14,J15,J16 | PCIe NVMe M.2 SSD Edge Connector | Amphenol ICC | MDT320M01001 | C4997055
33 | 4 | Q1,Q2,Q3,Q4 | MOSFET N | Vishay Intertech | 2N7002K-T1-GE3 | C81445
34 | 30 | R1,R3,R9,R10,R35,R54,R55,R56,R73,R75,R76,R78,R80,R81,R82,R83,R84,R87,R88,R89,R90,R91,R92,R133,R134,R139,R140,R145,R146,R151 | 330R | YAGEO | RC0201FR-07330RL | C274872
35 | 6 | R2,R4,R13,R14,R72,R115 | X_0R | YAGEO | RC0402JR-070RL | C60485
36 | 27 | R5,R6,R11,R12,R18,R19,R20,R21,R22,R25,R26,R27,R28,R29,R60,R62,R63,R67,R68,R116,R117,R120,R121,R122,R123,R128,R129 | 5.1K | YAGEO | RC0201FR-075K1L | C274341
37 | 2 | R7,R15 | 2.21K | SEI(Stackpole Elec) | RNCF0402DTE2K21 | C2485987
38 | 1 | R8 | 4.99K | SEI(Stackpole Elec) | RNCF0402DTE4K99 | C2484373
39 | 1 | R16 | 18k | YAGEO | RT0402DRD0718KL | C853550
40 | 1 | R17 | 1k | YAGEO | RC0201FR-071KL | C138165
41 | 1 | R23 | 200R1% | YAGEO | RC0201FR-07200RL | C274337
42 | 34 | R24,R37,R38,R93,R94,R95,R96,R97,R98,R99,R100,R101,R102,R103,R104,R105,R106,R107,R108,R109,R110,R111,R112,R113,R114,R118,R119,R124,R125,R126,R127,R130,R131,R132 | 0R | YAGEO | RC0402JR-070RL | C60485
43 | 2 | R30,R31 | X_470R | YAGEO | RC0201FR-07470RL | C295802
44 | 2 | R32,R39 | 200K | YAGEO | RC0201FR-07200KL | C138163
45 | 2 | R33,R34 | 1.15K | YAGEO | RC0201FR-071K15L | C474451
46 | 8 | R36,R57,R58,R74,R77,R79,R85,R86 | X_330R | YAGEO | RC0201FR-07330RL | C274872
47 | 14 | R40,R41,R42,R43,R44,R45,R46,R47,R48,R49,R50,R51,R52,R53 | 1.82K | YAGEO | RC0201FR-071K82L | C273321
48 | 8 | R59,R135,R136,R141,R142,R147,R148,R152 | 10K | YAGEO | RC0402FR-0710KL | C60490
49 | 7 | R61,R64,R65,R66,R69,R70,R71 | X_5.1K | YAGEO | RC0201FR-075K1L | C274341
50 | 7 | R137,R138,R143,R144,R149,R150,R153 | 330R | YAGEO | RC0402FR-07330RL | C105875
51 | 1 | S1 | X_SWPUSHBUTTON
52 | 1 | U1 | X_DSK_PWR_CONN | MOLEX | 462070004 | C585425
53 | 1 | U2 | ATX 6P | MOLEX | 457180002 | C17300543
54 | 3 | U3,U4,U5 | MYSGK4R030ERSR | Murata | MYSGK4R030ERSR
55 | 1 | U6 | MYMGK00510ERSR | Murata | MYMGK00510ERSR
56 | 1 | U7 | PI7C9X3G816 | Diodes Inc. | PI7C9X3G816GP
57 | 1 | U8 | AT25XE011-SSHN-T | RENESAS | AT25XE011-SSHN-T | C2061567
58 | 1 | U9 | LSF0108T20-13 | Diodes Incorporated | LSF0108T20-13
59 | 1 | U10 | SN74AXC8T245PWR | Texas Instruments | SN74AXC8T245PWR | C882718
60 | 1 | U11 | APX811-29UG-7 | Diodes Incorporated | APX811-29UG-7 | C110471
61 | 4 | U12,U13,U14,U15 | SN74LVC1G08DBVR | Texas Instruments | SN74LVC1G08DBVR | C7666

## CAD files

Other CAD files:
BOARD TEMPLATE/CNV & DXF FILES/PCIe_BOARD_TEMPLATE_FL.dxf

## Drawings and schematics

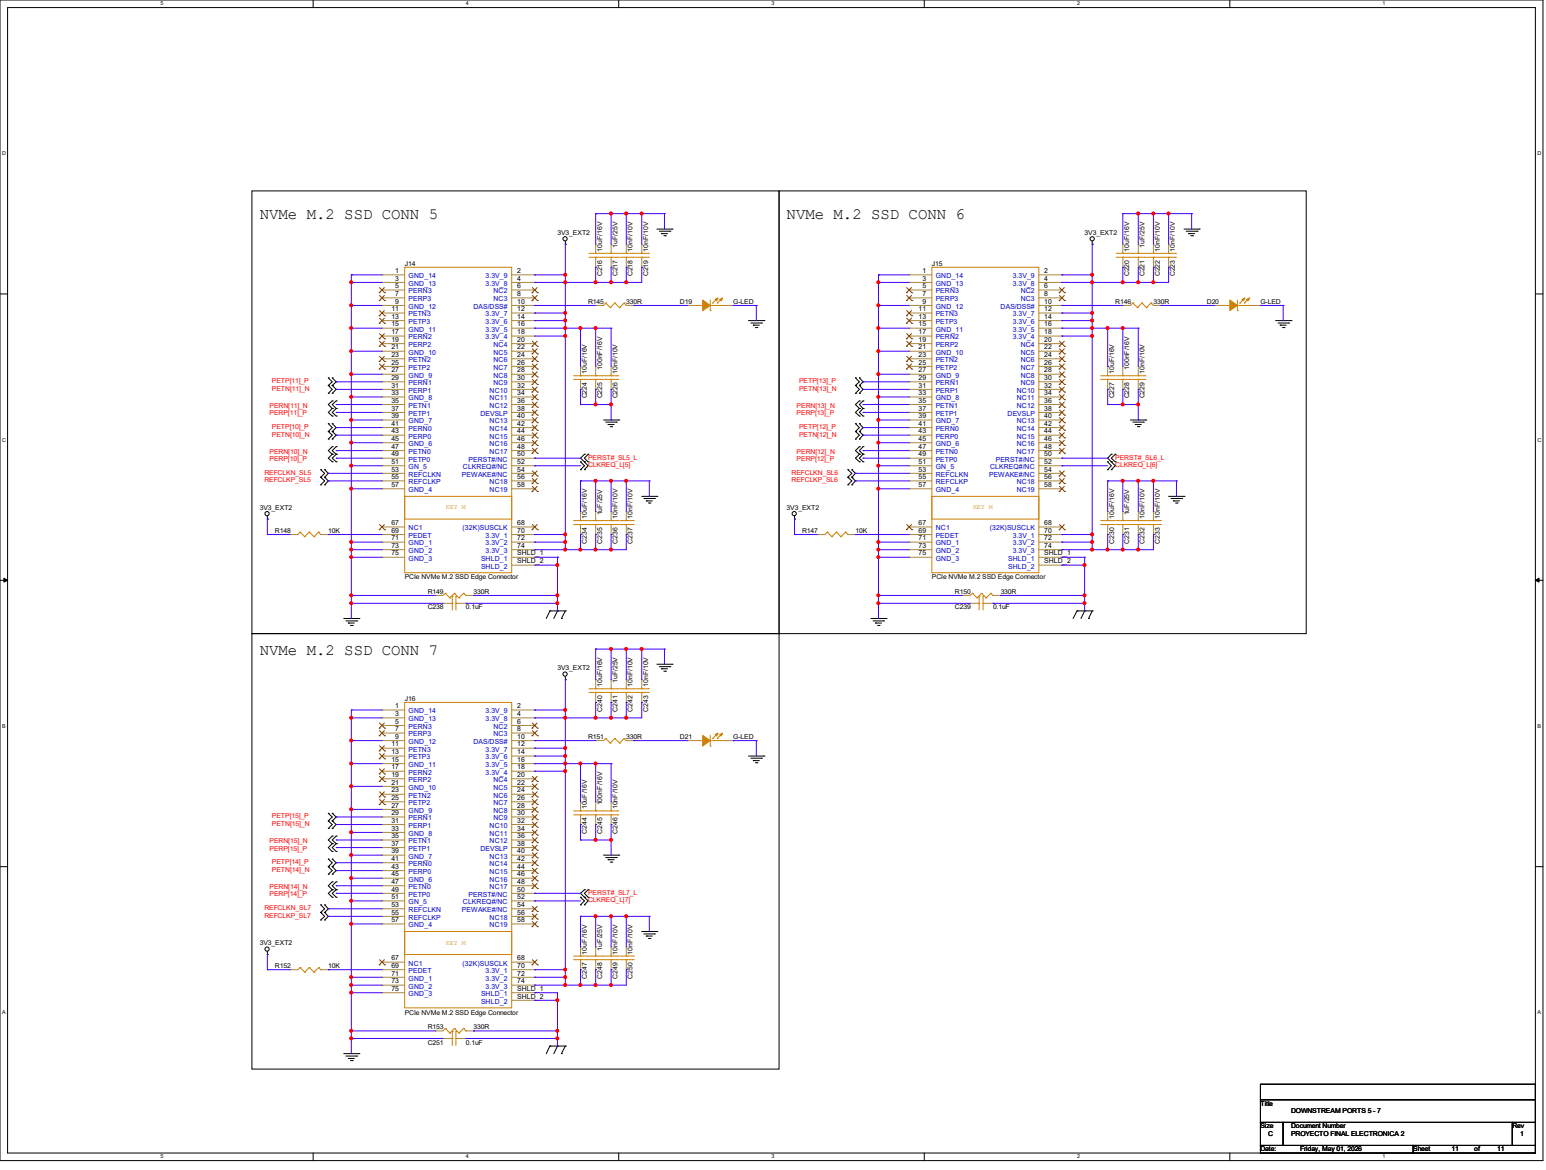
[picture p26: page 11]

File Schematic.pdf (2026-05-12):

5

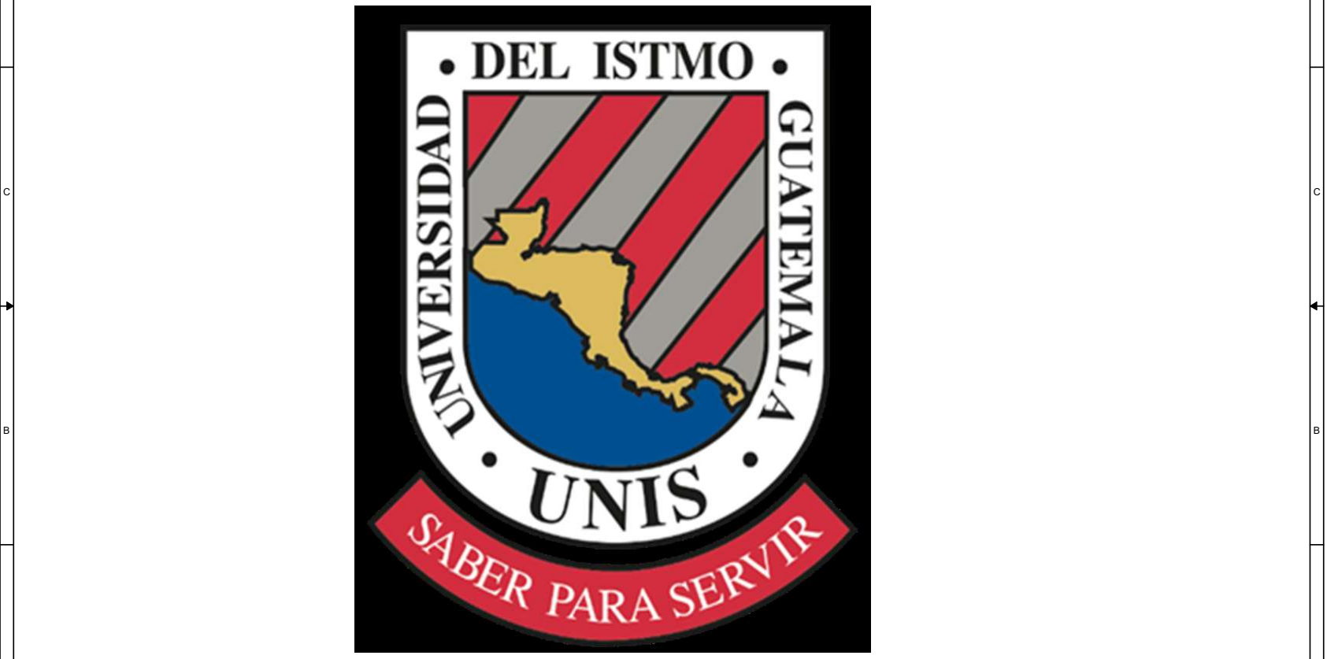
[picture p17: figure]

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
# MARZO DE 2026

# ELECTRONICA 2 Y DISENO ELECTRICO 1

# UNIVERSIDAD DEL ISTMO DE GUATEMALA FACULTAD DE INGENIERIA

# PROYECTO FINAL - PCIe NVMe M.2 SSD SWITCH

# MAXIMILIANO GONZALEZ

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
# PCIe INTERFACE

# PCIe SIDEBAND

# PCIe POWER

PG. #

# PCIe NVMe SWITCH - TABLE OF CONTENTS

6

# POWER

5

# PCIe EDGE CONNECTOR

4

7

3

# SECTION

11

9

# DOWNSTREAM PORTS 5 - 7

10

# RESET

PCIe CLOCK | 8

# DOWNSTREAM PORTS 1 - 4

3V3_GF | 12V_GF

## 3V3_AUX

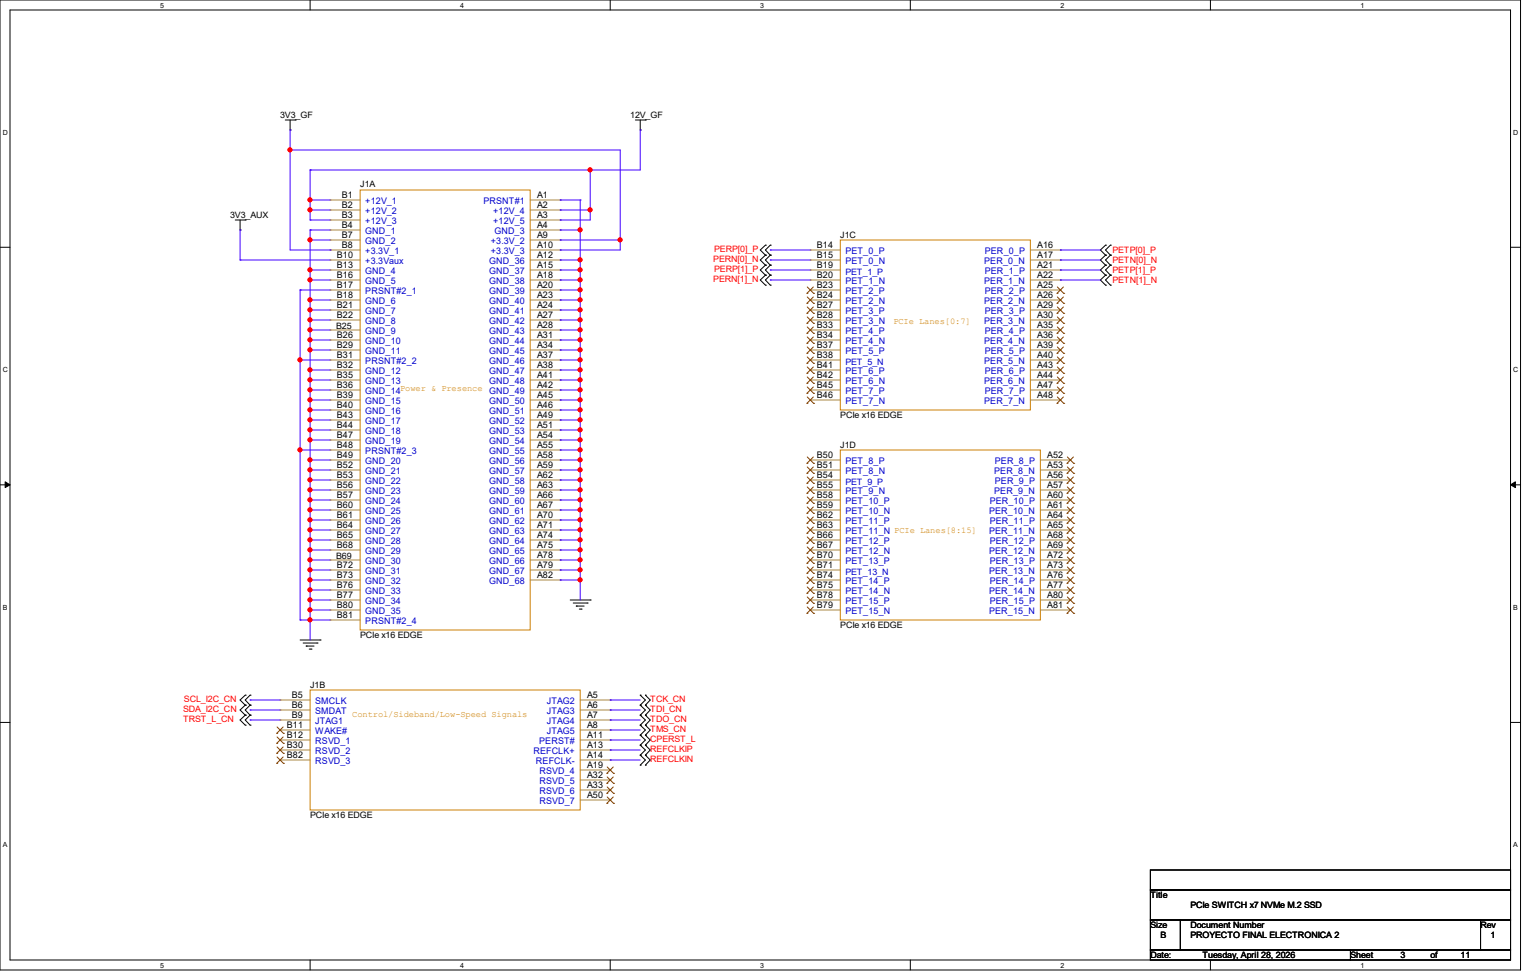
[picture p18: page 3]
REFCLKIN; REFCLKIP CPERST_L SCL_I2C_CN SDA_I2C_CN; PERP[0]_P PERN[0]_N PERP[1]_P PERN[1]_N; PETP[0]_P PETN[0]_N PETP[1]_P PETN[1]_N; TRST_L_CN; TDI_CN TDO_CN TMS_CN; TCK_CN; Title Size; Document Number; Rev Date:; Sheet; of PROYECTO FINAL ELECTRONICA 2; 1 PCIe SWITCH x7 NVMe M.2 SSD; Tuesday, April 28, 2026; 11 Title Size; Power & Presence J1A; PCIe x16 EDGE; PRSNT#1; A3 GND_3; A10 GND_36; A12 GND_37; A15 GND_38; A18 GND_39; A20 GND_40; A23 GND_41; A24 GND_42; A27 GND_43; A28 GND_44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

Control/Sideband/Low-Speed Signals J1B

# 12V POWER RAIL

3V3 POWER RAIL 1 | 1V8 POWER RAIL

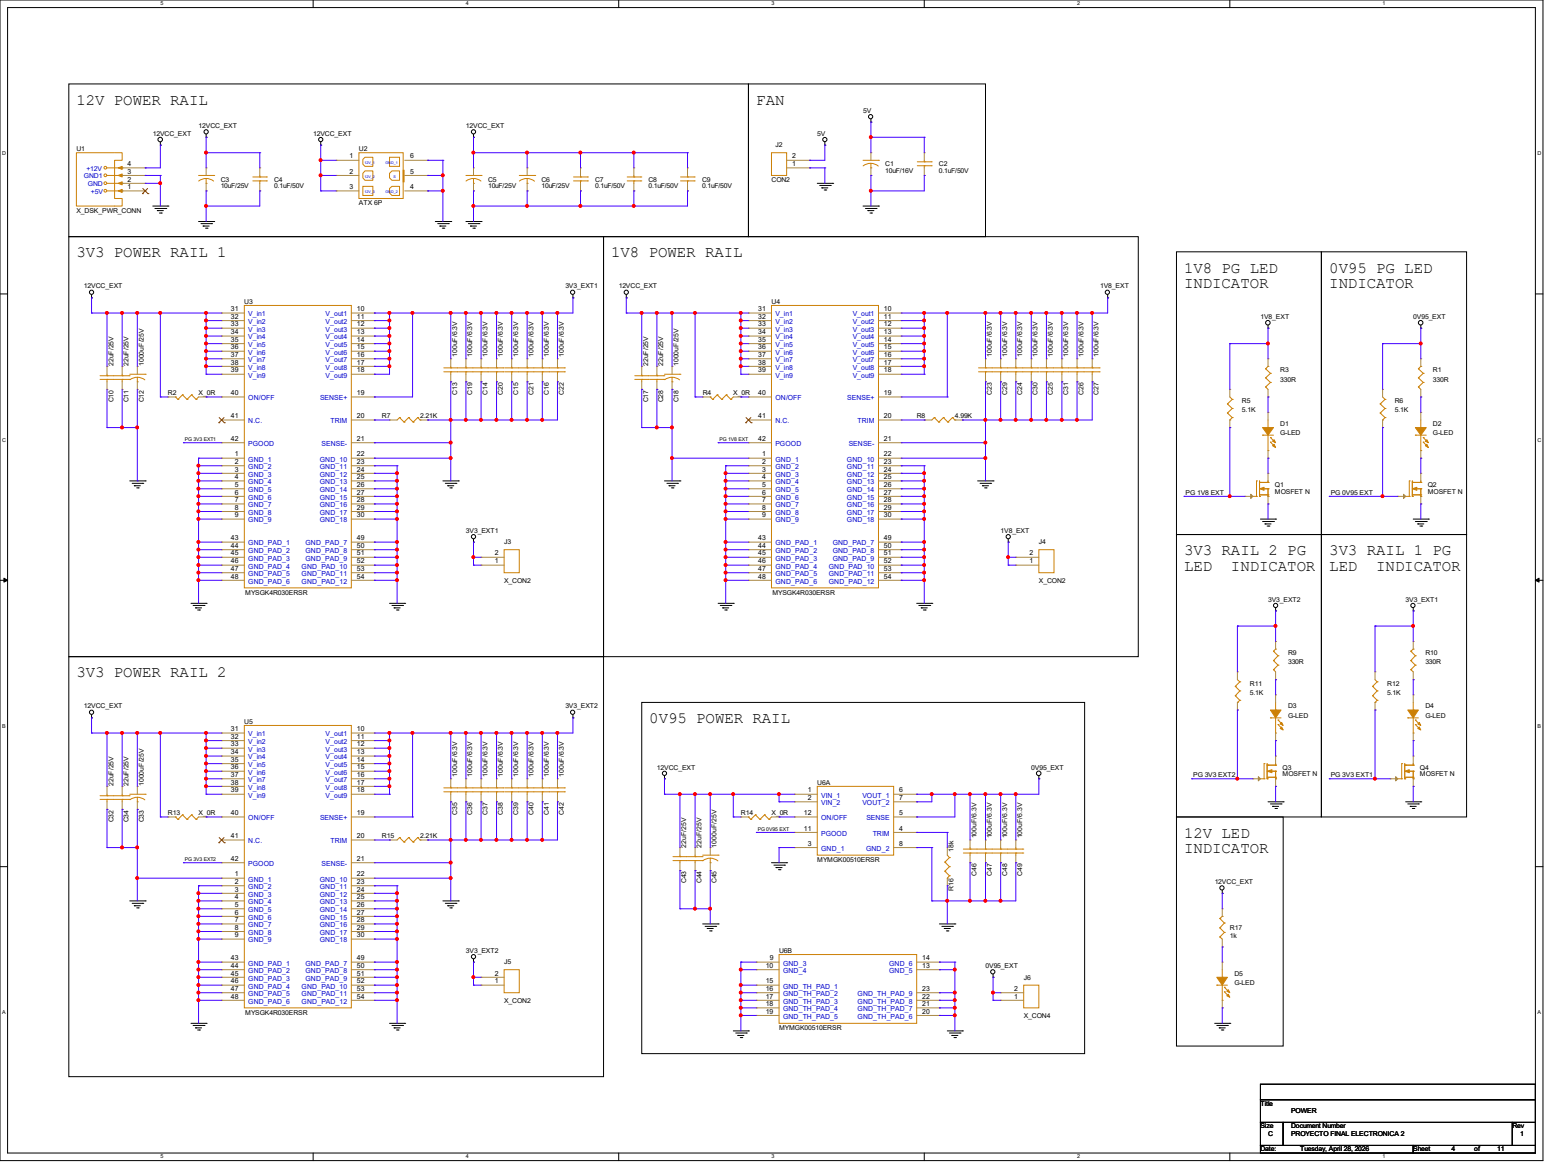
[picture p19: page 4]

2 C⁴⁸ ¹⁰⁰uF/6.3V C¹¹ ²²uF/25V

J7 | NC3 A5 | NC30
L6 | NC36 L7 | NC37 K1 | NC38 M1 | NC39 M3 | NC4 A6 | NC40 M4 | NC41 M5 | NC42 M6 | NC43 M7 | NC44 M8 | NC45 N1 | NC46 N2 | NC47 N3 | NC48 P1

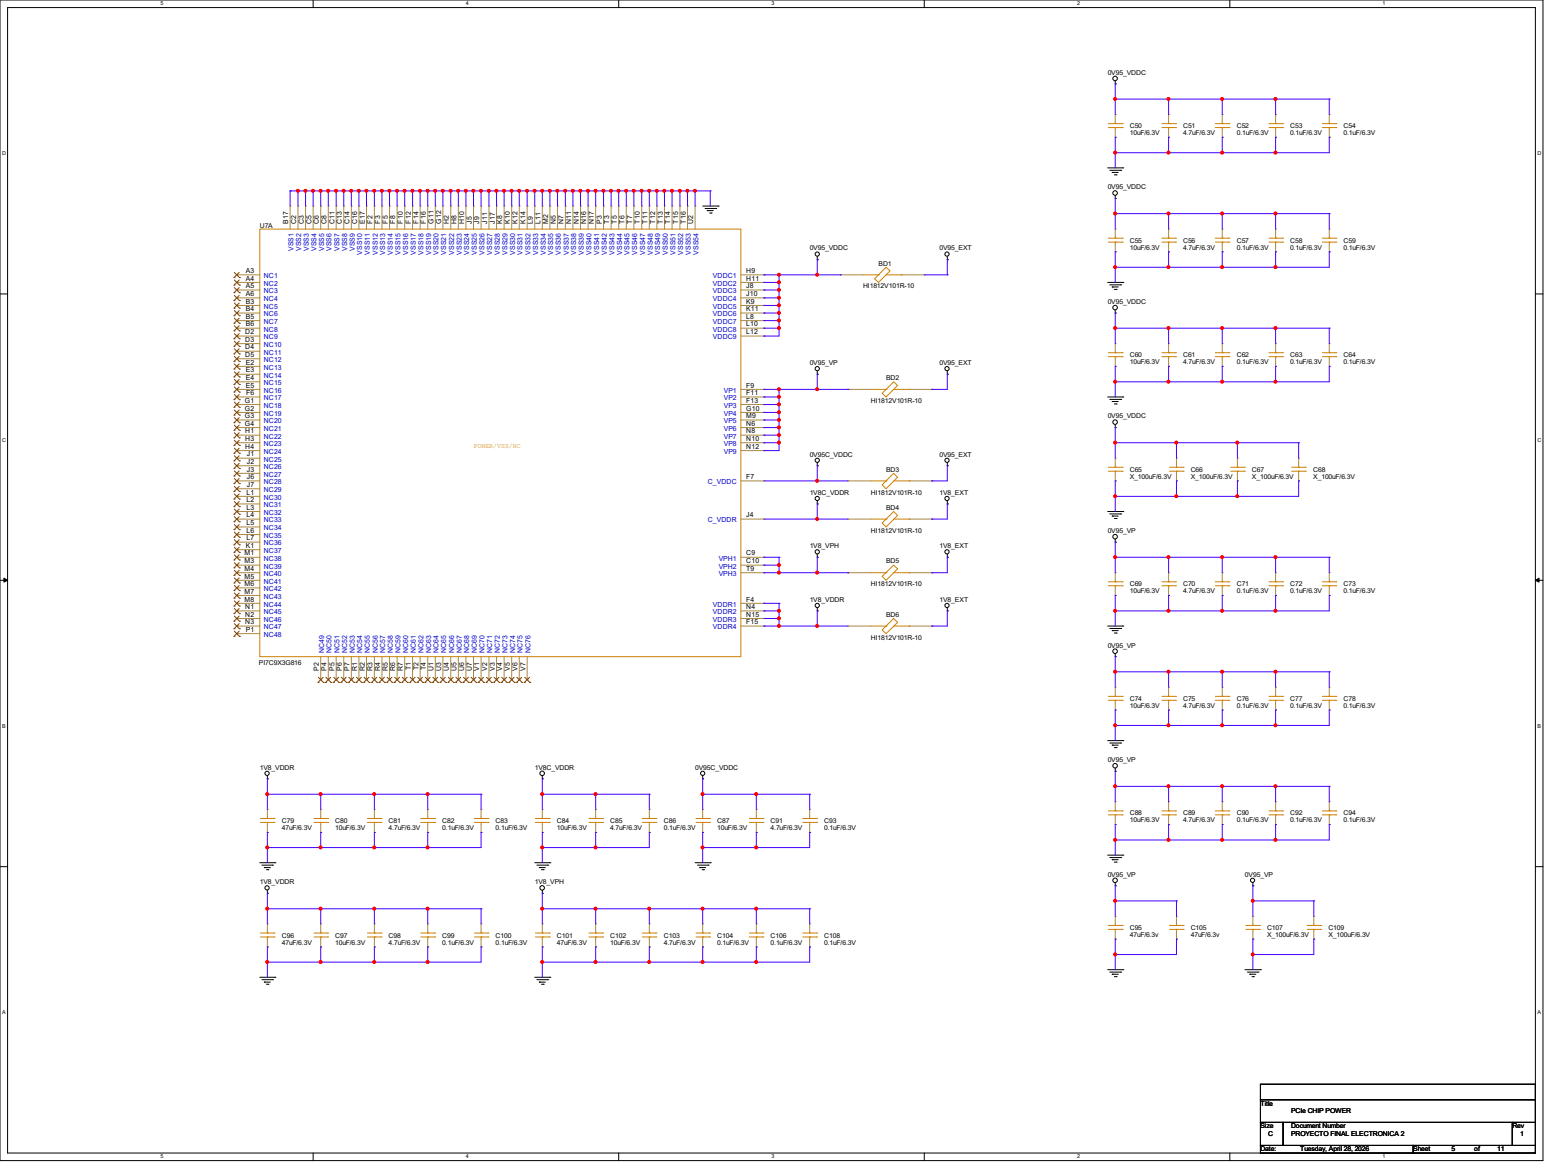
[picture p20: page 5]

P3

P1

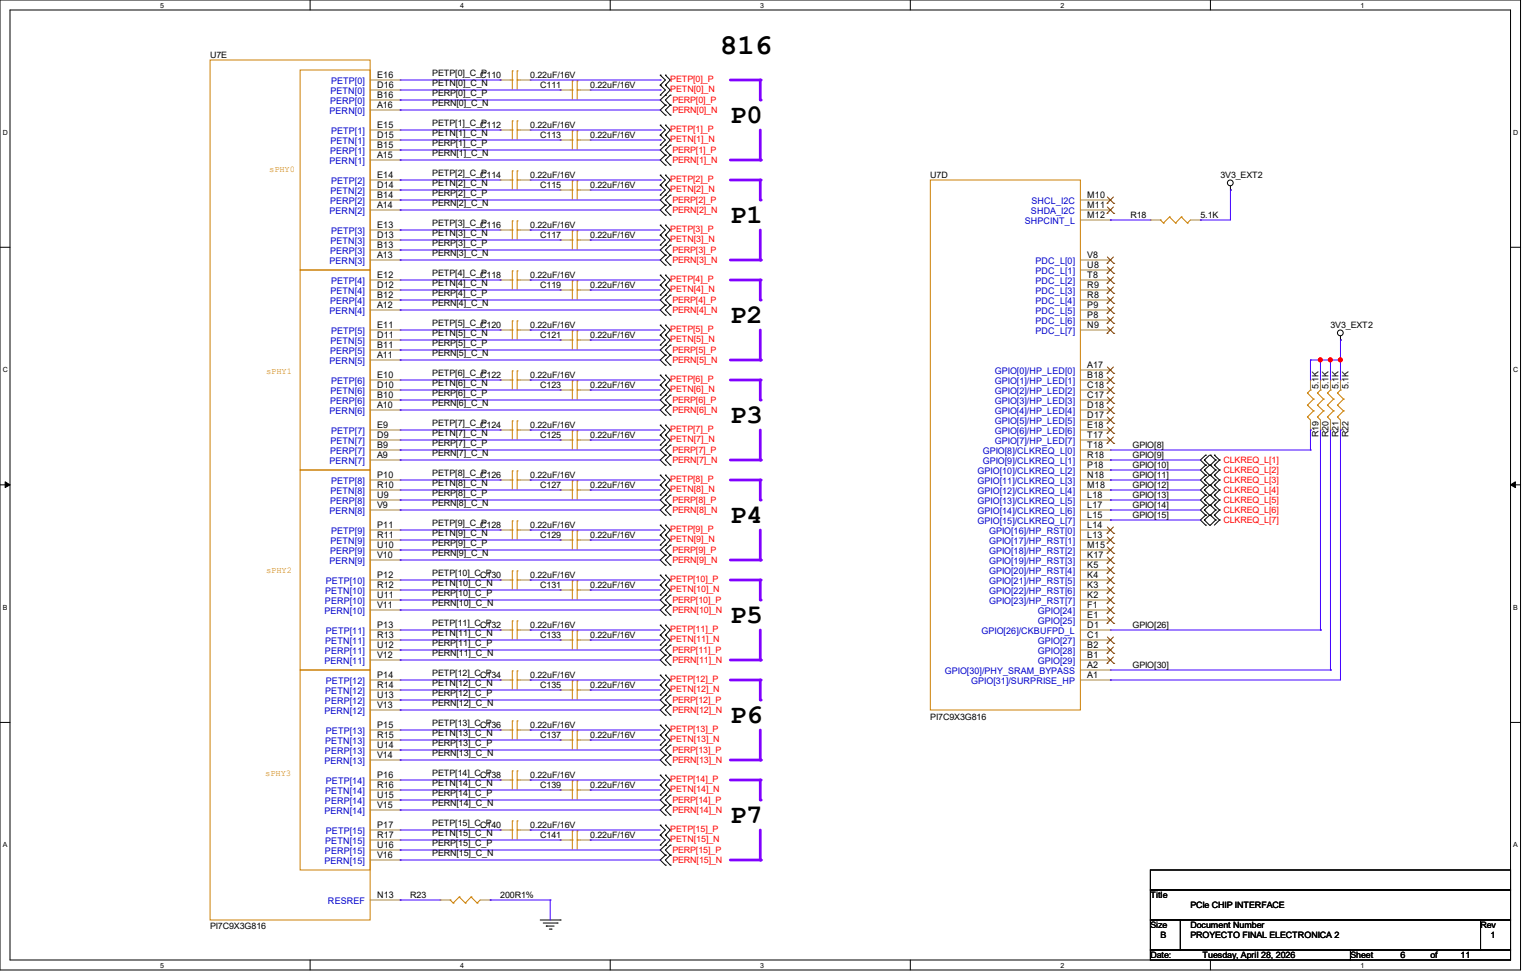
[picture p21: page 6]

PETN[0] D16
PERP[0] B16
PERN[0] A16
PETN[1] D15 PETN[2] D14 PETN[3] D13 PETN[4] D12 PETN[5] D11 PETN[6] D10 PETN[7] D9 PETN[8] R10 PETN[9] R11
PERP[1] B15 PERP[2] B14 PERP[3] B13 PERP[4] B12 PERP[5] B11 PERP[6] B10 PERP[7] B9 PERP[8] U9 PERP[9] U10
PERN[1] A15 PERN[2] A14 PERN[3] A13 PERN[4] A12 PERN[5] A11 PERN[6] A10 PERN[7] A9 PERN[8] V9 PERN[9] V10

PETP[7]_C_P
PETN[7]_C_N
PERP[7]_C_P
PERN[7]_C_N
PETP[10] P12 PETP[11] P13 PETP[12] P14 PETP[13] P15 PETP[14] P16 PETP[15] P17
PETN[10] R12 PETN[11] R13 PETN[12] R14 PETN[13] R15 PETN[14] R16 PETN[15] R17
PERP[10] U11 PERP[11] U12 PERP[12] U13 PERP[13] U14 PERP[14] U15 PERP[15] U16
PERN[10] V11 PERN[11] V12 PERN[12] V13 PERN[13] V14 PERN[14] V15 PERN[15] V16

GPIO[8] GPIO[9] GPIO[10] GPIO[11] GPIO[12] GPIO[13] GPIO[14] GPIO[15] GPIO[26] GPIO[30]

# LEVEL SHIFT 2 FOR JTAG

I2C | EEPROM

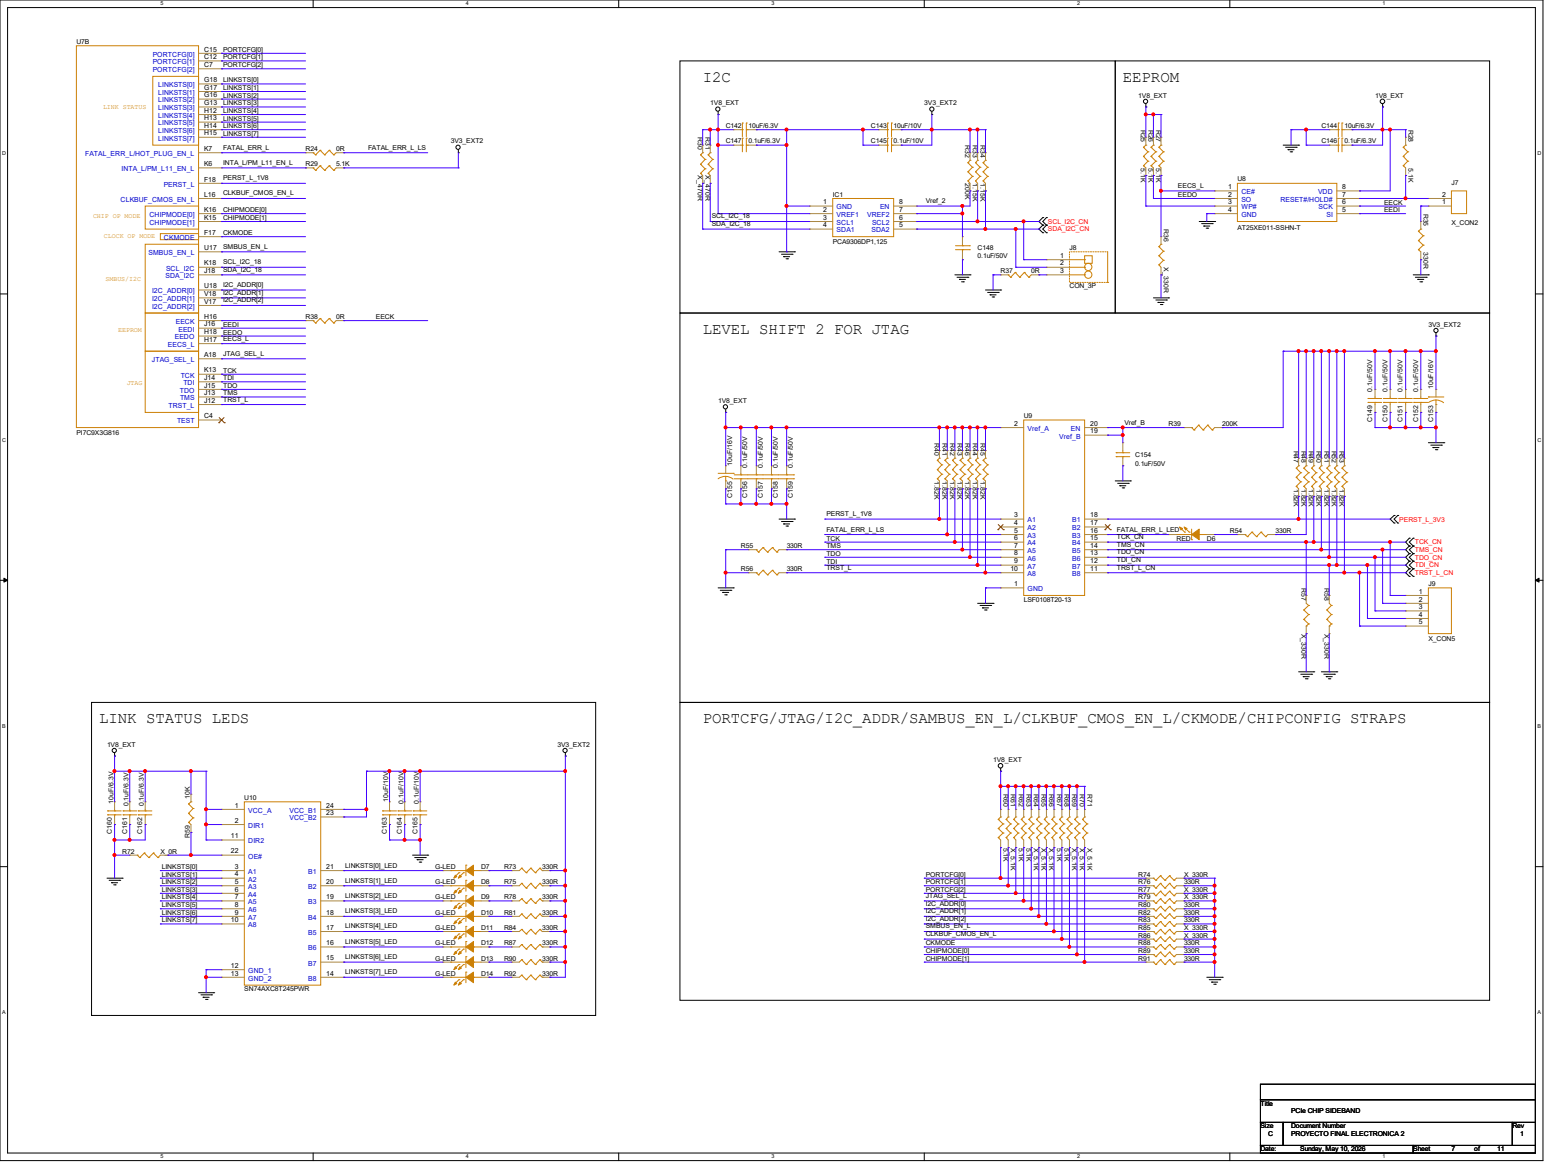
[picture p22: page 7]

PORTCFG/JTAG/I2C_ADDR/SAMBUS_EN_L/CLKBUF_CMOS_EN_L/CKMODE/CHIPCONFIG STRAPS

C C

# REFCLKIP REFCLKIN

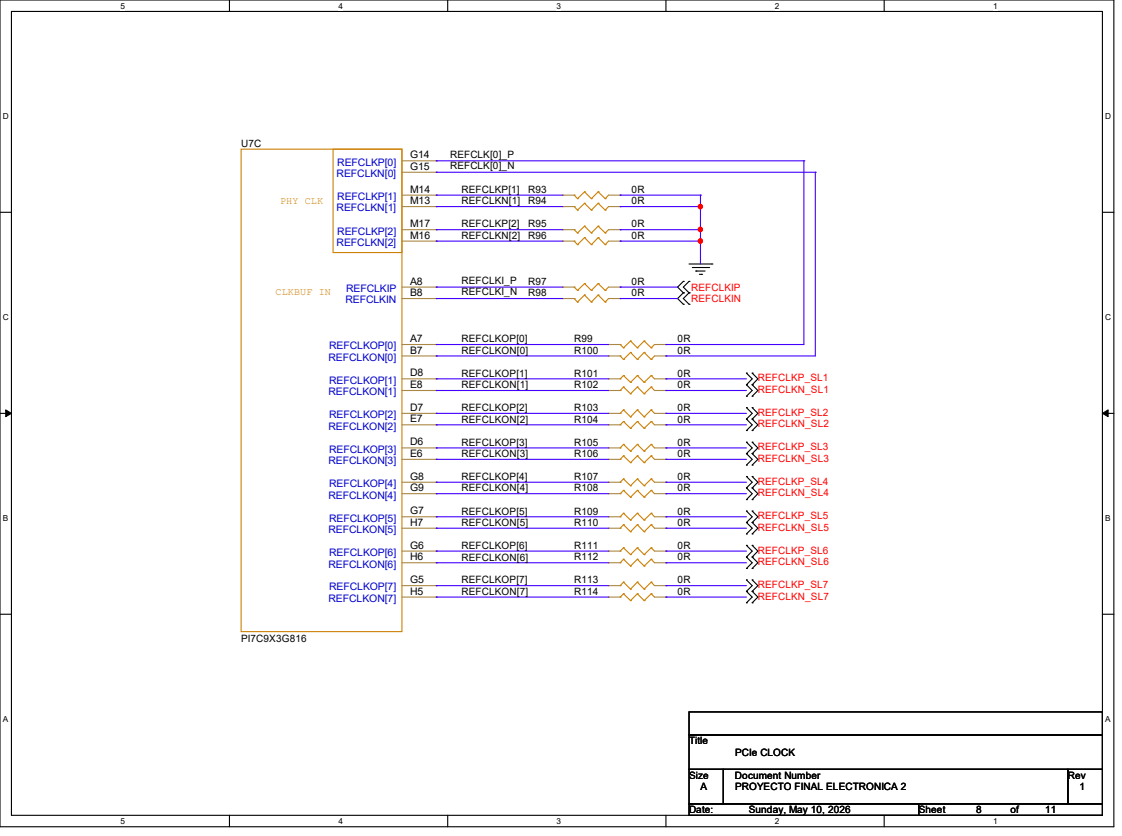
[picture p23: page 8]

# MANUAL RESET BTN

DOWNSTREAM PORTS 1 & 2 RESET | DOWNSTREAM PORTS 3 & 4 RESET

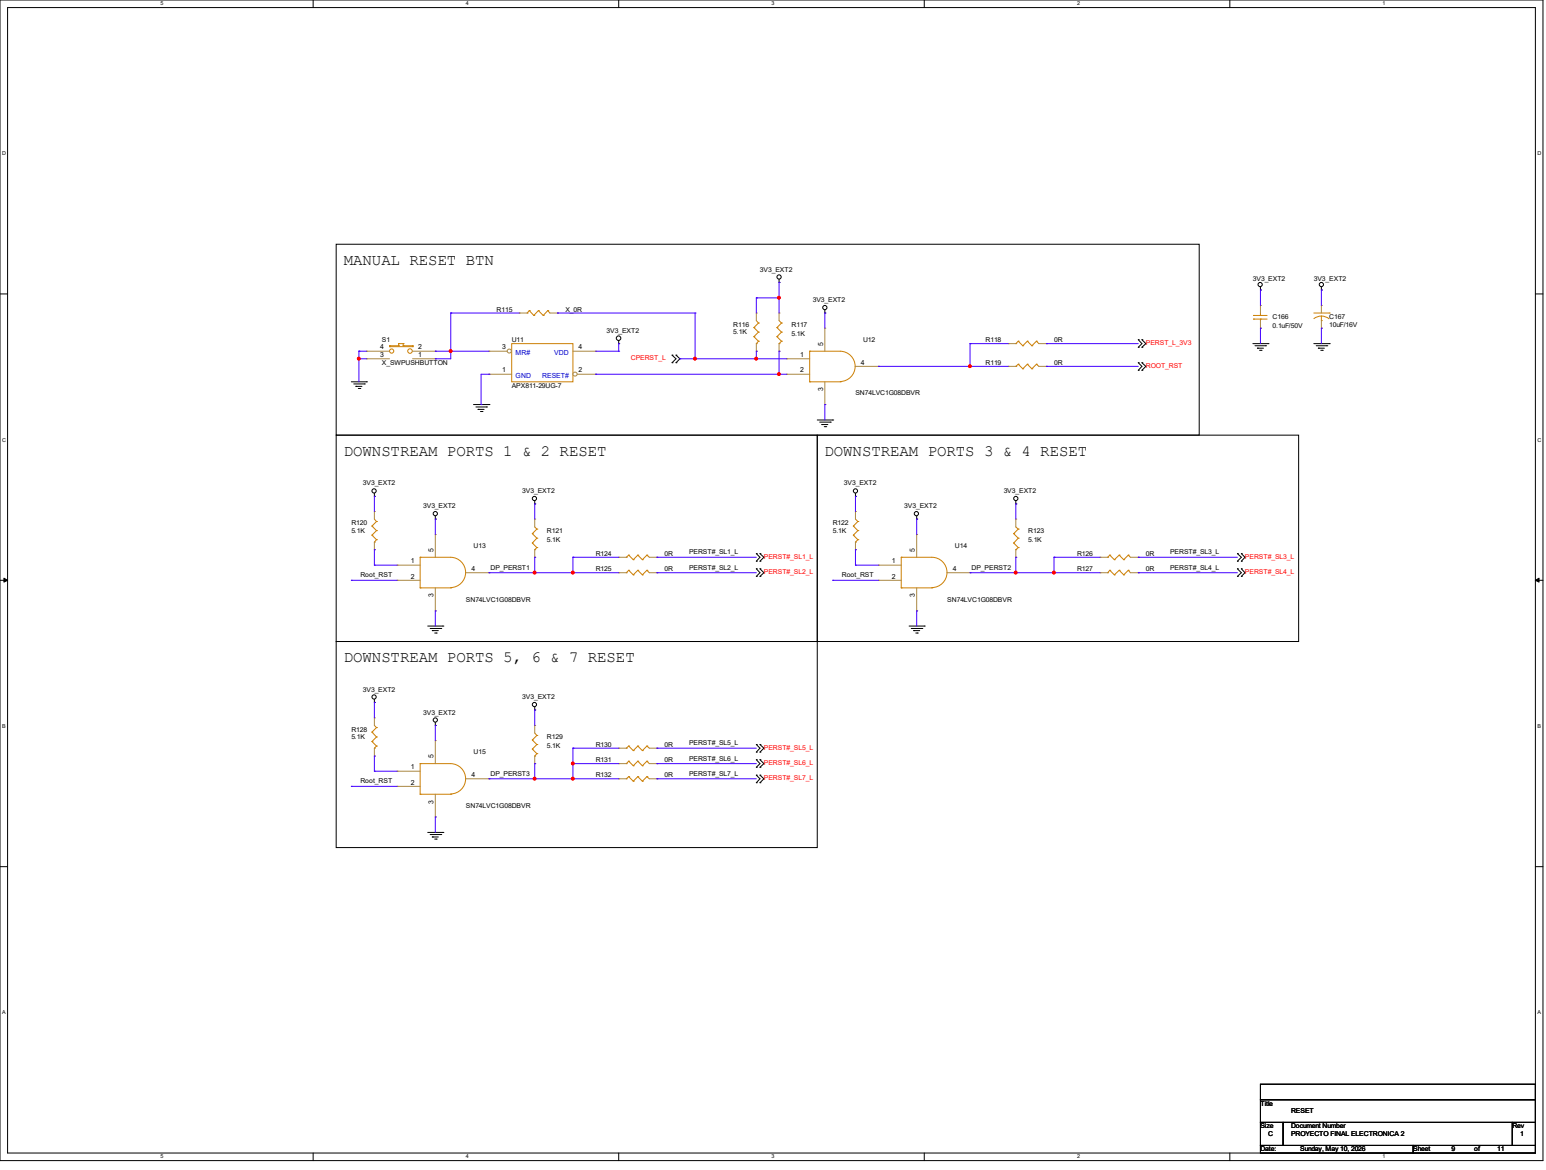
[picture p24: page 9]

NVMe M.2 SSD CONN 1 | NVMe M.2 SSD CONN 2

# J10 PCIe NVMe M.2 SSD Edge Connector GND_14

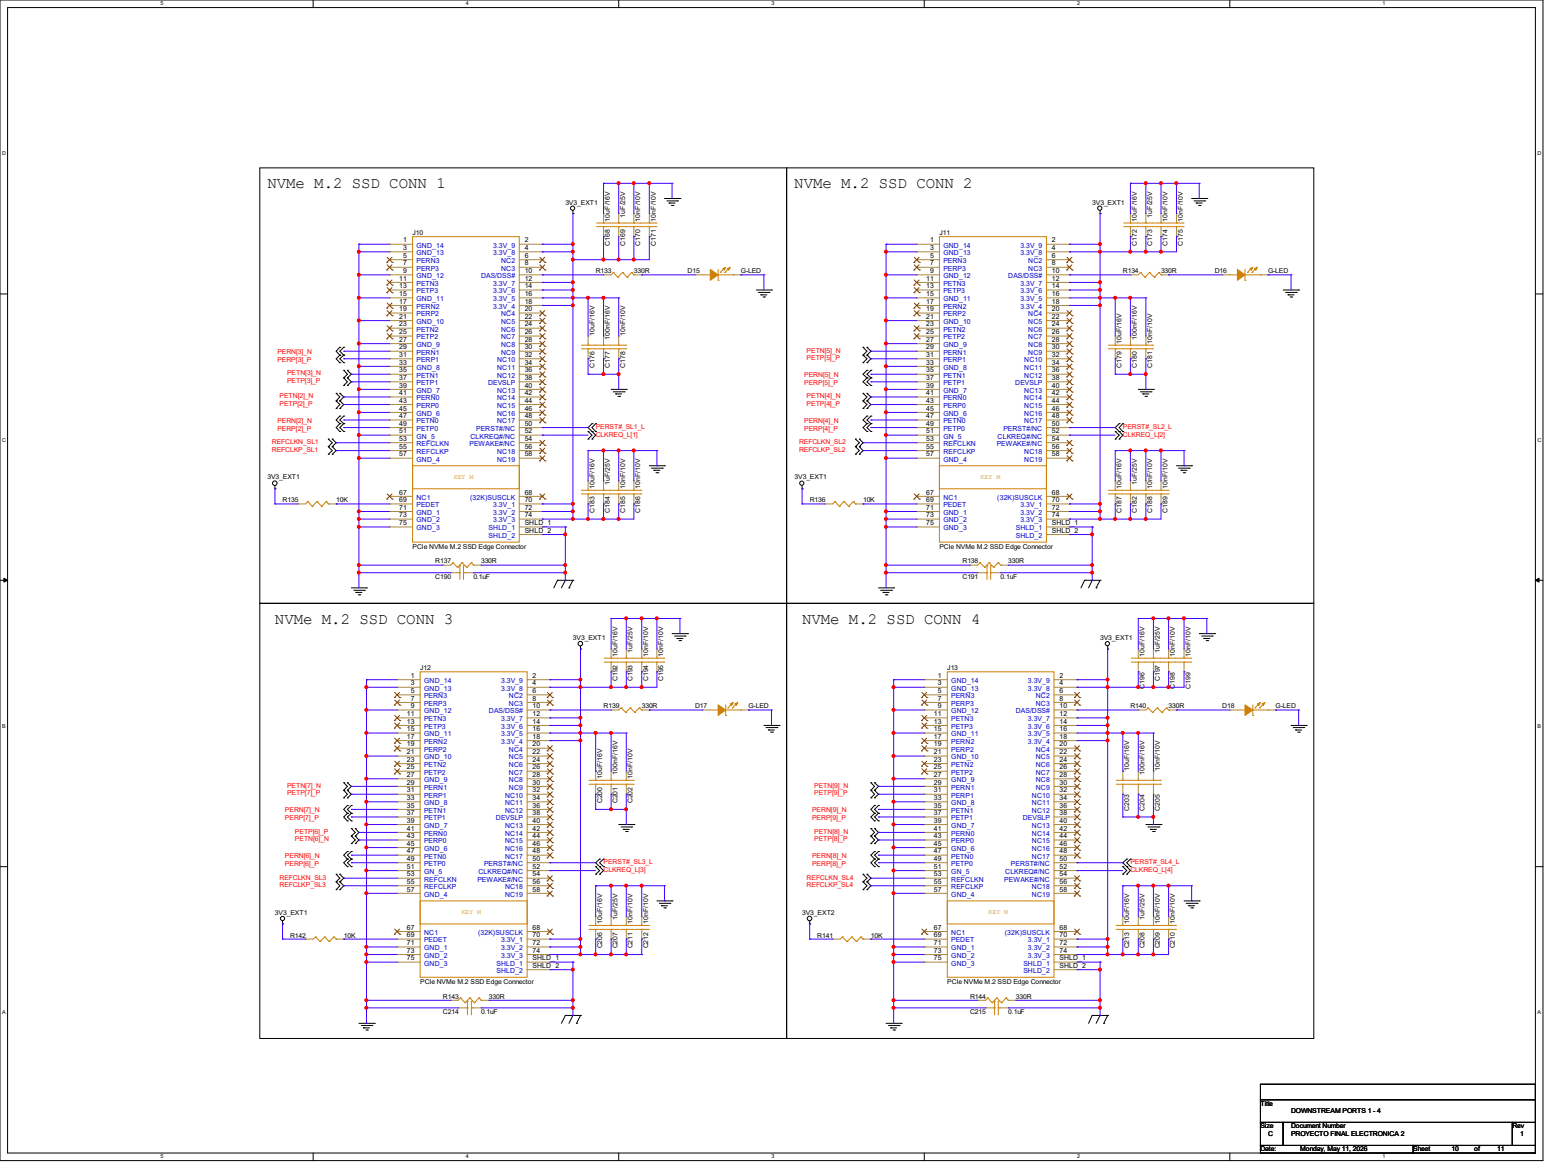
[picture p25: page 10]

NVMe M.2 SSD CONN 5 | NVMe M.2 SSD CONN 6

# J15 PCIe NVMe M.2 SSD Edge Connector GND_14
